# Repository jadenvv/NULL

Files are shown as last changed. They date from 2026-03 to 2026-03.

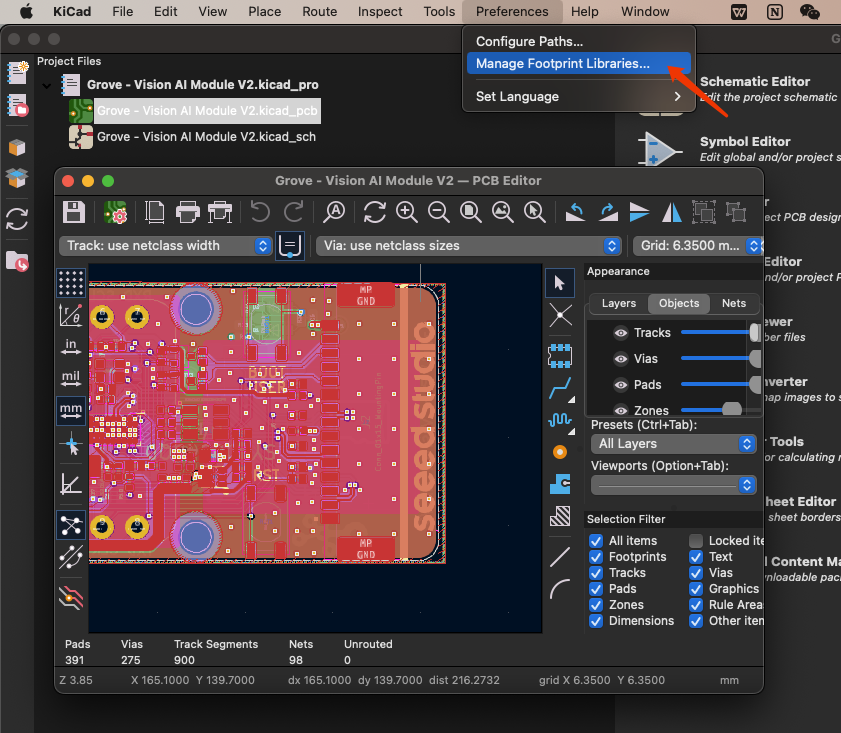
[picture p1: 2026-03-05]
null_elec/OPL_Kicad_Library-master/images/4.png

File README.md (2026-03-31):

# NULL: A Development Board for Pentesters
NULL is a ESP32-S3 based PCB board with capabilities of infrared emulation, RFID transceiving, ARP-spoofing on WiFi Networks, and LoRa Puck capabilities. Developed with a mixture of the ESP-IDF development environment 
## What was the motivation for NULL? 
The origins of the development of NULL really came out of the intrigue of the flipper zero. I wanted to create a cheaper alternative to what seemed like an amazing development board for pentesting enthuastist. And, not only did I create a cheaper alternative for myself, but added an additional feature of a LoRA puck boosting the overall usefullness of the board.
## Images of Schematic & Wiring 
Screenshot 2026-03-20 at 1 32 42 PM
4 Layer Board with the layout
<- SIGNAL  ->
<- GND  ->
<- POWER  ->
<- SIGNAL/GND  ->
Screenshot 2026-03-20 at 1 33 02 PM
Screenshot 2026-03-20 at 1 33 33 PM
Screenshot 2026-03-20 at 1 33 41 PM

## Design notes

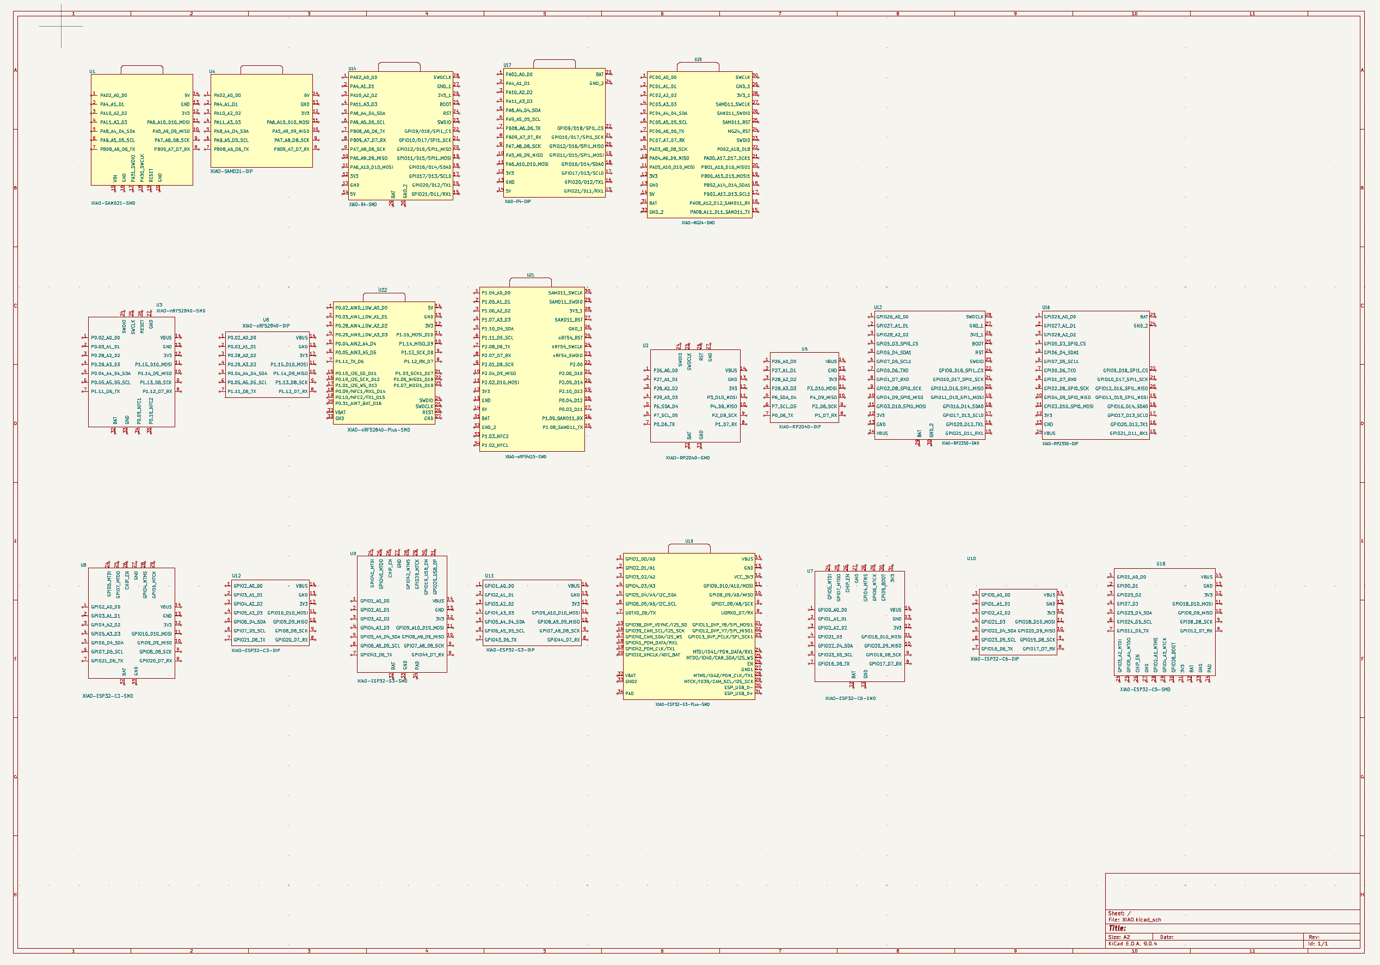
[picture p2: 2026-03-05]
null_elec/OPL_Kicad_Library-master/images/XIAO_Family_1.png

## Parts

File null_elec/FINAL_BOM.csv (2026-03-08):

JLCPCB BOM Tool - BOM Matching
BOM name：null-JLCPCB Assembly Order.xlsx |  | Download Time：2026-03-06 12:02:31 |  | * Our matching results are updated in real-time, but stock and prices may change. If it's been over 24 hours, please re-match before placing your order.
PCB Assembled Qty：5 |  | Est. Total Price：47.1463
Your BOM |  |  |  |  |  |  |  | Order Information
Top Designator | Comment | Footprint | Part # | Manufacturer | Footprint | Description | Category | JLCPCB Part # | Product link | Lib Type | Qty | Source | Total Price ($)
AE1 | Antenna | Connector_PinSocket_2.54mm:PinSocket_1x01_P2.54mm_Vertical
AE3 | Antenna | RF_Antenna:Molex_47948-0001_2.4Ghz | 479480001 | MOLEX | SMD,4x3.2mm | -40℃~+85℃ 100MHz 2.4GHz 2W 3.2mm 3.2mm 3.7dBi 50Ω Patch Antenna SMD,4x3.2mm Antennas ROHS | Antennas | C152351 | https://jlcpcb.com/partdetail/MOLEX-479480001/C152351 | Extended | 2 | 2 JLCPCB | 2.3406
C1,C4,C20,C21,C60 | 10uF | Capacitor_SMD:C_0805_2012Metric | GRM21BR61H106KE43L | Murata Electronics | 805 | 10uF 50V X5R ±10% 0805 Multilayer Ceramic Capacitors MLCC - SMD/SMT ROHS | Multilayer Ceramic Capacitors MLCC - SMD/SMT | C440198 |  | Basic | 14 | 14 JLCPCB | 0.9156
C2,C14,C28,C29,C32 | 1uF | Capacitor_SMD:C_0402_1005Metric | CL05A105KA5NQNC | Samsung Electro-Mechanics | 402 | 1uF 25V X5R ±10% 0402 Multilayer Ceramic Capacitors MLCC - SMD/SMT ROHS | Multilayer Ceramic Capacitors MLCC - SMD/SMT | C52923 | https://jlcpcb.com/partdetail/53938-CL05A105KA5NQNC/C52923 | Basic | 20 | 20 JLCPCB | 0.066
C3 | 10nF | Capacitor_SMD:C_0805_2012Metric | CL21B103KBANNNC | Samsung Electro-Mechanics | 805 | 10nF 50V X7R ±10% 0805 Multilayer Ceramic Capacitors MLCC - SMD/SMT ROHS | Multilayer Ceramic Capacitors MLCC - SMD/SMT | C1710 | https://jlcpcb.com/partdetail/2062-CL21B103KBANNNC/C1710 | Basic | 20 | 20 JLCPCB | 0.13
C5,C11,C22 | 1nF | Capacitor_SMD:C_0402_1005Metric | 0402B102K500NT | FH (Guangdong Fenghua Advanced Tech) | 402 | 1nF 50V X7R ±10% 0402 Multilayer Ceramic Capacitors MLCC - SMD/SMT ROHS | Multilayer Ceramic Capacitors MLCC - SMD/SMT | C1523 | https://jlcpcb.com/partdetail/1875-0402B102K500NT/C1523 | Basic | 20 | 20 JLCPCB | 0.024
C6,C7,C8,C9,C10,C30, C15,C16,C15,C16 | 0.1uF | Capacitor_SMD:C_0402_1005Metric | CL05B104KO5NNNC | Samsung Electro-Mechanics | 402 | 100nF 16V X7R ±10% 0402 Multilayer Ceramic Capacitors MLCC - SMD/SMT ROHS | Multilayer Ceramic Capacitors MLCC - SMD/SMT | C1525 | https://jlcpcb.com/partdetail/1877-CL05B104KO5NNNC/C1525 | Basic | 26 | 26 JLCPCB | 0.0338
C12,C13 | 12pF | Capacitor_SMD:C_0402_1005Metric | 0402CG120J500NT | FH (Guangdong Fenghua Advanced Tech) | 402 | 12pF 50V C0G ±5% 0402 Multilayer Ceramic Capacitors MLCC - SMD/SMT ROHS | Multilayer Ceramic Capacitors MLCC - SMD/SMT | C1547 | https://jlcpcb.com/partdetail/1899-0402CG120J500NT/C1547 | Basic | 20 | 20 JLCPCB | 0.022
C17,C18,C19 | 470nF | Capacitor_SMD:C_0402_1005Metric | CL05A474KP5NNNC | Samsung Electro-Mechanics | 402 | 10V 470nF X5R ±10% 0402 Multilayer Ceramic Capacitors MLCC - SMD/SMT ROHS | Multilayer Ceramic Capacitors MLCC - SMD/SMT | C47339 | https://jlcpcb.com/partdetail/48344-CL05A474KP5NNNC/C47339 | Extended | 20 | 20 JLCPCB | 0.084
C23 | 39pF | Capacitor_SMD:C_0402_1005Metric | 0402CG390J500NT | FH (Guangdong Fenghua Advanced Tech) | 402 | 39pF 50V C0G ±5% 0402 Multilayer Ceramic Capacitors MLCC - SMD/SMT ROHS | Multilayer Ceramic Capacitors MLCC - SMD/SMT | C1563 | https://jlcpcb.com/partdetail/1915-0402CG390J500NT/C1563 | Extended | 20 | 20 JLCPCB | 0.024
C24,C25 | 3.3pF | Capacitor_SMD:C_0402_1005Metric | 0402CG3R3C500NT | FH (Guangdong Fenghua Advanced Tech) | 402 | 3.3pF 50V C0G 0402 Multilayer Ceramic Capacitors MLCC - SMD/SMT ROHS | Multilayer Ceramic Capacitors MLCC - SMD/SMT | C1565 | https://jlcpcb.com/partdetail/1917-0402CG3R3C500NT/C1565 | Extended | 20 | 20 JLCPCB | 0.026
C26 | 4.7uF | Capacitor_SMD:C_0402_1005Metric | CL05A475MP5NRNC | Samsung Electro-Mechanics | 402 | 10V 4.7uF X5R ±20% 0402 Multilayer Ceramic Capacitors MLCC - SMD/SMT ROHS | Multilayer Ceramic Capacitors MLCC - SMD/SMT | C23733 | https://jlcpcb.com/partdetail/24469-CL05A475MP5NRNC/C23733 | Basic | 20 | 20 JLCPCB | 0.1
C27,C57 | 10uF | Capacitor_SMD:C_0402_1005Metric | CL05A106MQ5NUNC | Samsung Electro-Mechanics | 402 | 10uF 6.3V X5R ±20% 0402 Multilayer Ceramic Capacitors MLCC - SMD/SMT ROHS | Multilayer Ceramic Capacitors MLCC - SMD/SMT | C15525 | https://jlcpcb.com/partdetail/16204-CL05A106MQ5NUNC/C15525 | Basic | 20 | 20 JLCPCB | 0.11
C31,C33,C39,C41,C46,C58 | 2.2uF | Capacitor_SMD:C_0402_1005Metric | GRM155R60J225KE95D | Murata Electronics | 402 | 2.2uF 6.3V X5R ±10% 0402 Multilayer Ceramic Capacitors MLCC - SMD/SMT ROHS | Multilayer Ceramic Capacitors MLCC - SMD/SMT | C76992 | https://jlcpcb.com/partdetail/MurataElectronics-GRM155R60J225KE95D/C76992 | Extended | 22 | 22 JLCPCB | 0.176
C34,C40,C42,C47,C59 | 0.01uF | Capacitor_SMD:C_0402_1005Metric | CL05B103KB5NNNC | Samsung Electro-Mechanics | 402 | 10nF 50V X7R ±10% 0402 Multilayer Ceramic Capacitors MLCC - SMD/SMT ROHS | Multilayer Ceramic Capacitors MLCC - SMD/SMT | C15195 | https://jlcpcb.com/partdetail/15869-CL05B103KB5NNNC/C15195 | Basic | 20 | 20 JLCPCB | 0.028
C35,C36 | 1.6pF | Capacitor_SMD:C_0402_1005Metric | GJM1555C1H1R6WB01D | Murata Electronics | 402 | 1.6pF 50V C0G 0402 Multilayer Ceramic Capacitors MLCC - SMD/SMT ROHS | Multilayer Ceramic Capacitors MLCC - SMD/SMT | C88881 | https://jlcpcb.com/partdetail/MurataElectronics-GJM1555C1H1R6WB01D/C88881 | Extended | 8 | 8 JLCPCB | 0.464
C37,C38,C54 | 27pF | Capacitor_SMD:C_0402_1005Metric | GJM1555C1H270FB01D | Murata Electronics | 402 | 27pF 50V C0G ±1% 0402 Multilayer Ceramic Capacitors MLCC - SMD/SMT ROHS | Multilayer Ceramic Capacitors MLCC - SMD/SMT | C88883 | https://jlcpcb.com/partdetail/MurataElectronics-GJM1555C1H270FB01D/C88883 | Extended | 20 | 20 JLCPCB | 0.598
C43,C44 | 1500uF | Capacitor_SMD:C_0402_1005Metric | RX1500UF10V90RV0042 | KNSCHA | SMD,D10xL10.2mm | -55℃~+105℃ 10.2mm 10V 10mm 1500uF 2000hrs@105℃ ±20% SMD,D10xL10.2mm Aluminum Electrolytic Capacitors - SMD ROHS | Aluminum Electrolytic Capacitors - SMD | C2887277 | https://jlcpcb.com/partdetail/KNSCHA-RX1500UF10V90RV0042/C2887277 | Extended | 5 | 5 JLCPCB | 1.187
C45,C48 | 1200pF | Capacitor_SMD:C_0402_1005Metric | CC0402KRX7R9BB122 | YAGEO | 402 | 1.2nF 50V X7R ±10% 0402 Multilayer Ceramic Capacitors MLCC - SMD/SMT ROHS | Multilayer Ceramic Capacitors MLCC - SMD/SMT | C107021 | https://jlcpcb.com/partdetail/YAGEO-CC0402KRX7R9BB122/C107021 | Extended | 20 | 20 JLCPCB | 0.024
C49,C52 | 680pF | Capacitor_SMD:C_0402_1005Metric | 0402B681K500NT | FH (Guangdong Fenghua Advanced Tech) | 402 | 50V 680pF X7R ±10% 0402 Multilayer Ceramic Capacitors MLCC - SMD/SMT ROHS | Multilayer Ceramic Capacitors MLCC - SMD/SMT | C1541 | https://jlcpcb.com/partdetail/1893-0402B681K500NT/C1541 | Extended | 20 | 20 JLCPCB | 0.024
C50 | 10pF | Capacitor_SMD:C_0402_1005Metric | CL05C100JB5NNNC | Samsung Electro-Mechanics | 402 | 10pF 50V C0G ±5% 0402 Multilayer Ceramic Capacitors MLCC - SMD/SMT ROHS | Multilayer Ceramic Capacitors MLCC - SMD/SMT | C32949 | https://jlcpcb.com/partdetail/33914-CL05C100JB5NNNC/C32949 | Basic | 20 | 20 JLCPCB | 0.09
C51 | 220pF | Capacitor_SMD:C_0402_1005Metric | 0402B221K500NT | FH (Guangdong Fenghua Advanced Tech) | 402 | 220pF 50V X7R ±10% 0402 Multilayer Ceramic Capacitors MLCC - SMD/SMT ROHS | Multilayer Ceramic Capacitors MLCC - SMD/SMT | C1530 | https://jlcpcb.com/partdetail/1882-0402B221K500NT/C1530 | Basic | 20 | 20 JLCPCB | 0.024
C53 | 120pF | Capacitor_SMD:C_0402_1005Metric | 0402N121J500CT | Walsin Tech Corp | 402 | 120pF 50V NP0 ±5% 0402 Multilayer Ceramic Capacitors MLCC - SMD/SMT ROHS | Multilayer Ceramic Capacitors MLCC - SMD/SMT | C237176 | https://jlcpcb.com/partdetail/Walsin_TechCorp-0402N121J500CT/C237176 | Extended | 20 | 20 JLCPCB | 0.036
C55 | 82pF | Capacitor_SMD:C_0402_1005Metric | 0402CG820J500NT | FH (Guangdong Fenghua Advanced Tech) | 402 | 50V 82pF C0G ±5% 0402 Multilayer Ceramic Capacitors MLCC - SMD/SMT ROHS | Multilayer Ceramic Capacitors MLCC - SMD/SMT | C45501 | https://jlcpcb.com/partdetail/46503-0402CG820J500NT/C45501 | Extended | 20 | 20 JLCPCB | 0.024
C56 | 68pF | Capacitor_SMD:C_0402_1005Metric | CL05C680JB5NNNC | Samsung Electro-Mechanics | 402 | 50V 68pF C0G ±5% 0402 Multilayer Ceramic Capacitors MLCC - SMD/SMT ROHS | Multilayer Ceramic Capacitors MLCC - SMD/SMT | C14441 | https://jlcpcb.com/partdetail/15103-CL05C680JB5NNNC/C14441 | Extended | 20 | 20 JLCPCB | 0.092
D1 | IR26-21C_L110_TR8 | LED_SMD:LED_1206_3216Metric | IR26-21C/L110/TR8 | Everlight Elec | 1206 | -25℃~+85℃ 1.2V 1mW/sr@IF=20mA 940nm 1206 Infrared LED Emitters ROHS | Infrared LED Emitters | C73929 | https://jlcpcb.com/partdetail/EverlightElec-IR26_21C_L110TR8/C73929 | Extended | 6 | 6 JLCPCB | 0.2892
D2 | ESD9B3.3ST5G | Diode_SMD:D_SOD-923 | ESD9B3.3ST5G | GOODWORK | SOD-923 | -55℃~+150℃ 1 100W 10pF 12.5V 3.3V 4.3V 500nA 8A ESD IEC 61000-4-2 SOD-923 ESD and Surge Protection (TVS/ESD) ROHS | ESD And Surge Protection (TVS/ESD) | C41364470 | https://jlcpcb.com/partdetail/GOODWORK-ESD9B33ST5G/C41364470 | Extended | 20 | 20 JLCPCB | 0.376
D3 | 1N4148 | Diode_THT:D_DO-35_SOD27_P7.62mm_Horizontal | 1N4148 | Changzhou Starsea Elec | DO-35 | -65℃~+200℃@(Tj) 100V 150mA 1V@10mA 4ns 500mA 500mW 5uA@75V DO-35 Switching Diodes ROHS | Switching Diodes | C85057 | https://jlcpcb.com/partdetail/Changzhou_StarseaElec-1N4148/C85057 | Extended | 7 | 7 JLCPCB | 0.0854
IC1 | TRF7970ARHBR | trt:QFN50P500X500X100-33N-D | TRF7970ARHBR | Texas Instruments | VQFN-32-EP(5x5) | 106Kbit/s、212Kbit/s、424Kbit/s、848Kbit/s 13.56MHz 2.7V~5.5V FeliCa,ISO 14443A,ISO 14443B,ISO 15693,ISO 18000-3,ISO 21481,MIFARE,NFC SPI VQFN-32-EP(5x5) RFID ICs ROHS | RFID ICs | C117004 | https://jlcpcb.com/partdetail/TexasInstruments-TRF7970ARHBR/C117004 | Extended | 2 | 2 JLCPCB | 3.8788
J1 | USB_C_Receptacle_USB2.0_14P | Connector_USB:USB_C_Receptacle_HCTL_HC-TYPE-C-16P-01A | HC-TYPE-C-16P-01A | HCTL | SMD | -55℃~+85℃ 1 16P 20V 5A 7.35mm Black Female Surface Mount, Right Angle Type-C SMD USB Connectors ROHS | USB Connectors | C2894897 | https://jlcpcb.com/partdetail/HCTL-HC_TYPE_C_16P01A/C2894897 | Extended | 2 | 2 JLCPCB | 0.1966
L1 | 2.0nH | Inductor_SMD:L_0402_1005Metric | LQG15HS2N0S02D | Murata Electronics | 402 | 2nH 6GHz 8@100MHz 900mA 90mΩ 0402 Inductors (SMD) ROHS | Inductors (SMD) | C18216 | https://jlcpcb.com/partdetail/MurataElectronics-LQG15HS2N0S02D/C18216 | Extended | 20 | 20 JLCPCB | 0.2
L2 | 150nH | Inductor_SMD:L_0402_1005Metric | LQG15HSR15J02D | Murata Electronics | 402 | 150mA 150nH 2.99Ω 550MHz 8@100MHz Multilayer inductor ±5% 0402 Inductors (SMD) ROHS | Inductors (SMD) | C162548 | https://jlcpcb.com/partdetail/MurataElectronics-LQG15HSR15J02D/C162548 | Extended | 20 | 20 JLCPCB | 0.194
L3,L4 | 15uH | Inductor_SMD:L_0402_1005Metric | LQW15DN150M00D | Murata Electronics | 402 | 100mA 100mA 15uH 6.555Ω ±20% 0402 Power Inductors ROHS | Inductors (SMD) | C3221788 | https://jlcpcb.com/partdetail/ChilisinElec-SDT0402T_150MN/C329840 | Extended | 8 | 8 JLCPCB | 9.71
L5 | 9.1nH | Inductor_SMD:L_0402_1005Metric | LQG15HS9N1J02D | Murata Electronics | 402 | 260mΩ 3.4GHz 500mA 8@100MHz 9.1nH Multilayer inductor ±5% 0402 Inductors (SMD) ROHS | Inductors (SMD) | C162547 | https://jlcpcb.com/partdetail/MurataElectronics-LQG15HS9N1J02D/C162547 | Extended | 20 | 20 JLCPCB | 0.176
L6 | 2.6nH | Inductor_SMD:L_0402_1005Metric | LQG15WZ2N6B02D | Murata Electronics | 402 | 2.6nH 23@250MHz 6.5GHz 70mΩ 900mA AEC-Q200 0402 Inductors (SMD) ROHS | Inductors (SMD) | C1012745 | https://jlcpcb.com/partdetail/MurataElectronics-LQG15WZ2N6B02D/C1012745 | Extended | 5 | 5 JLCPCB | 0.4495
L7 | 330nH | Inductor_SMD:L_0402_1005Metric | VHF100505HQR33JT | FH (Guangdong Fenghua Advanced Tech) | 402 | 330nH 350MHz 50mA 6@50MHz 7Ω ±5% 0402 Inductors (SMD) ROHS | Inductors (SMD) | C485776 | https://jlcpcb.com/partdetail/494209-VHF100505HQR33JT/C485776 | Extended | 20 | 20 JLCPCB | 0.206
L8 | 4.7uH | Inductor_SMD:L_0402_1005Metric | IHLP1616BZER4R7M5A | Vishay Intertech | SMD,4.5x4.1mm | 1.8A 110mΩ 4.7uH AEC-Q200 ±20% SMD,4.5x4.1mm Power Inductors ROHS | Power Inductors | C3223759 | https://jlcpcb.com/partdetail/VishayIntertech-IHLP1616BZER4R7M5A/C3223759 | Extended | 5 | 5 JLCPCB | 2.527
Q1 | PN2222A | Package_TO_SOT_THT:TO-92_Inline | PN2222ABU | onsemi | TO-92-3L | -55℃~+150℃ 1 NPN 10uA 1A 300MHz 300mV 35 40V 625mW 6V NPN TO-92-3L Bipolar (BJT) ROHS | Bipolar (BJT) | C896866 | https://jlcpcb.com/partdetail/onsemi-PN2222ABU/C896866 | Extended | 4 | 4 JLCPCB | 0.4316
R1,R2,R3,R5,R6,R22 | 0 | Resistor_SMD:R_0402_1005Metric | 0402WGF0000TCE | UNI-ROYAL(Uniroyal Elec) | 402 | -55℃~+155℃ 0Ω 50V 62.5mW Thick Film Resistor ±1% ±800ppm/℃ 0402 Chip Resistor - Surface Mount ROHS | Chip Resistor - Surface Mount | C17168 | https://jlcpcb.com/partdetail/17853-0402WGF0000TCE/C17168 | Basic | 22 | 22 JLCPCB | 0.0198
R4,R14,R15,R16,R18,R19,R20,R21,R26,R27,R28 | 10K | Resistor_SMD:R_0402_1005Metric | 0402WGF1002TCE | UNI-ROYAL(Uniroyal Elec) | 402 | -55℃~+155℃ 10kΩ 50V 62.5mW Thick Film Resistor ±1% ±100ppm/℃ 0402 Chip Resistor - Surface Mount ROHS | Chip Resistor - Surface Mount | C25744 | https://jlcpcb.com/partdetail/26487-0402WGF1002TCE/C25744 | Basic | 32 | 32 JLCPCB | 0.0256
R7,R8 | 5.1K | Resistor_SMD:R_0402_1005Metric | 0402WGF5101TCE | UNI-ROYAL(Uniroyal Elec) | 402 | -55℃~+155℃ 5.1kΩ 50V 62.5mW Thick Film Resistor ±1% ±100ppm/℃ 0402 Chip Resistor - Surface Mount ROHS | Chip Resistor - Surface Mount | C25905 | https://jlcpcb.com/partdetail/26648-0402WGF5101TCE/C25905 | Basic | 20 | 20 JLCPCB | 0.016
R9,R11 | 22 | Resistor_SMD:R_0402_1005Metric | 0402WGF220JTCE | UNI-ROYAL(Uniroyal Elec) | 402 | -55℃~+155℃ 22Ω 50V 62.5mW Thick Film Resistor ±1% ±100ppm/℃ 0402 Chip Resistor - Surface Mount ROHS | Chip Resistor - Surface Mount | C25092 | https://jlcpcb.com/partdetail/25835-0402WGF220JTCE/C25092 | Basic | 20 | 20 JLCPCB | 0.016
R10 | 100 | Resistor_SMD:R_0402_1005Metric | 0402WGF1000TCE | UNI-ROYAL(Uniroyal Elec) | 402 | -55℃~+155℃ 100Ω 50V 62.5mW Thick Film Resistor ±1% ±100ppm/℃ 0402 Chip Resistor - Surface Mount ROHS | Chip Resistor - Surface Mount | C25076 | https://jlcpcb.com/partdetail/25819-0402WGF1000TCE/C25076 | Basic | 20 | 20 JLCPCB | 0.016
R12 | 50 | Resistor_SMD:R_0402_1005Metric | AC0402JR-0750RL | YAGEO | 402 | -55℃~+155℃ 50V 50Ω 62.5mW Thick Film Resistor ±100ppm/℃ ±5% 0402 Chip Resistor - Surface Mount ROHS | Chip Resistor - Surface Mount | C227387 | https://jlcpcb.com/partdetail/YAGEO-AC0402JR0750RL/C227387 | Extended | 20 | 20 JLCPCB | 0.018
R13 | 650 | Resistor_SMD:R_0402_1005Metric | ERJ2RKF6650X | PANASONIC | 402 | -55℃~+155℃ 100mW 50V 665Ω Thick Film Resistor ±1% ±100ppm/℃ 0402 Chip Resistor - Surface Mount ROHS | Chip Resistor - Surface Mount | C2076870 | https://jlcpcb.com/partdetail/PANASONIC-ERJ2RKF6650X/C2076870 | Extended | 20 | 20 JLCPCB | 0.11
R17 | 390K | Resistor_SMD:R_0402_1005Metric | RCT02390KJLF | HKR(Hong Kong Resistors) | 402 | -55℃~+155℃ 390kΩ 50V 62.5mW Thick Film Resistor ±200ppm/℃ ±5% 0402 Chip Resistor - Surface Mount ROHS | Chip Resistor - Surface Mount | C174227 | https://jlcpcb.com/partdetail/185617-RCT02390KJLF/C174227 | Extended | 20 | 20 JLCPCB | 0.04
R23 | 750 | Resistor_SMD:R_0402_1005Metric | RCA02750RFLF | HKR(Hong Kong Resistors) | 402 | -55℃~+155℃ 50V 62.5mW 750Ω Thick Film Resistor ±1% ±200ppm/℃ 0402 Chip Resistor - Surface Mount ROHS |  | C22369358 | https://jlcpcb.com/partdetail/23848388-RCA02750RFLF/C22369358 | Extended | 7 | 7 JLCPCB | 0.0042
SW1 | SW_SPST | Button_Switch_SMD:SW_SPST_SKQG_WithStem | SKQGAKE010 | ALPSALPINE | SMD-4P,5.2x5.2mm | -30℃~+85℃ 1.5mm 100,000 cycles 12V 3.43N 5.2mm 5.2mm 50mA No Round Button SMD(SMT) Tab SPST Surface Mount,Vertical Without Bracket SMD-4P,5.2x5.2mm Tactile Switches ROHS | Tactile Switches | C127478 | https://jlcpcb.com/partdetail/ALPSALPINE-SKQGAKE010/C127478 | Extended | 5 | 5 JLCPCB | 0.869
SW2,SW3,SW4,SW5 | SW_Push | Button_Switch_SMD:SW_Tactile_SPST_NO_Straight_CK_PTS636Sx25SMTRLFS | PTS636SM43LFS | C&K | 插件,6x3.5mm | -40℃~+90℃ 1.8N 12V 3.5mm 50mA 6mm IP40 No PC Pin Rectangular Button SPST-NO Through Hole 插件,6x3.5mm Tactile Switches ROHS | Tactile Switches | C2689636 | https://jlcpcb.com/partdetail/CK-PTS636SM43LFS/C2689636 | Extended | 12 | 12 JLCPCB | 2.4696
U1 | W25Q32JVSS | Package_SO:SOIC-8_5.3x5.3mm_P1.27mm | W25Q32JVSSIQ | Winbond Elec | SOIC-8-208mil | -40℃~+85℃ 100,000 cycles 10uA 120ms@(32KB) 133MHz 2.7V~3.6V 20 Years 32Mbit 3ms SPI SOIC-8-208mil NOR FLASH ROHS | NOR FLASH | C82344 | https://jlcpcb.com/partdetail/WinbondElec-W25Q32JVSSIQ/C82344 | Extended | 2 | 2 JLCPCB | 3.007
U2 | ESP32-S3 | Package_DFN_QFN:QFN-56-1EP_7x7mm_P0.4mm_EP4x4mm | ESP32-S3 | Espressif Systems | QFN-56-EP(7x7) | -40℃~+105℃ -98.4dBm 150Mbps 2.412GHz~2.484GHz 2.4GHz 21dBm 340mA 3V~3.6V 88mA SPI、USB、UART、ADC、I2C、I2S、PWM WiFi transceiver QFN-56-EP(7x7) RF Transceiver ICs ROHS | RF Transceiver ICs | C2913192 | https://jlcpcb.com/partdetail/EspressifSystems-ESP32S3/C2913192 | Extended | 2 | 2 JLCPCB | 5.9952
U3 | TSOP343xx | OptoDevice:Vishay_MOLD-3Pin | TSOP4838 | Vishay Intertech | SIP-3-2.54mm | -25℃~+85℃ 2.5V~5.5V 38kHz 45m 45° 700uA SIP-3-2.54mm Infrared Remote Receiver (IRM) ROHS | Infrared Remote Receiver (IRM) | C124647 | https://jlcpcb.com/partdetail/VishayIntertech-TSOP4838/C124647 | Extended | 2 | 2 JLCPCB | 2.407
U5 | SX1262IMLTRT | Package_DFN_QFN:QFN-24-1EP_4x4mm_P0.5mm_EP2.6x2.6mm | SX1262IMLTRT | SEMTECH | QFN-24-EP(4x4) | -148dBm -40℃~+85℃ 1.8V~3.7V 150MHz~960MHz 22dBm 300Kbps 32mA 4.2mA ISM SPI transceiver QFN-24-EP(4x4) RF Transceiver ICs ROHS | RF Transceiver ICs | C191341 | https://jlcpcb.com/partdetail/SEMTECH-SX1262IMLTRT/C191341 | Extended | 2 | 2 JLCPCB | 6.592
U6 | PE4259 | Package_TO_SOT_SMD:SOT-363_SC-70-6 | PE4259-63 | pSemi | SC-70-6 | -40℃~+85℃ 0.35dB 1.8V~3.3V 10MHz~3GHz 30dB 33.5dBm SPDT SC-70-6 RF Switches ROHS | RF Switches | C470892 | https://jlcpcb.com/partdetail/pSemi-PE425963/C470892 | Extended | 2 | 2 JLCPCB | 1.232
U7 | NCP1117-3.3_SOT223 | Package_TO_SOT_SMD:SOT-223-3_TabPin2 | AMS1117-3.3(SOT-223) | HXY MOSFET | SOT-223 | 0℃~+125℃@(Ta) 1 1.4V@(1A) 15V 1A 3.3V Fixed Positive SOT-223 Voltage Regulators - Linear, Low Drop Out (LDO) Regulators ROHS | Voltage Regulators - Linear, Low Drop Out (LDO) Regulators | C5346136 | https://jlcpcb.com/partdetail/HXYMOSFET-AMS1117_3_3_SOT_223/C5346136 | Extended | 6 | 6 JLCPCB | 0.2412
U8 | TPS61222DCK | Package_TO_SOT_SMD:Texas_R-PDSO-G6 | TPS61222DCKR | Texas Instruments | SC-70-6(SOT-363) | -40℃~+125℃@(TJ) 1 200mA 5V 700mV~5.5V Boost Boost Built-in Fixed Yes SC-70-6(SOT-363) DC-DC Converters ROHS | DC-DC Converters | C116461 | https://jlcpcb.com/partdetail/TexasInstruments-TPS61222DCKR/C116461 | Extended | 2 | 2 JLCPCB | 1.115
U9 | APS6404L-3SQRx-SN | Package_SO:SOIC-8_3.9x4.9mm_P1.27mm | APS6404L-3SQR-SN | AP Memory | SOP-8 | SOP-8 PSRAM ROHS | DRAM | C5333729 | https://jlcpcb.com/partdetail/APMemory-APS6404L_3SQRSN/C5333729 | Extended | 2 | 2 JLCPCB | 5.1266
Y1 | 40MHz | Crystal:Crystal_SMD_3225-4Pin_3.2x2.5mm | X3S040000B81H-R | HELE(Harmony Elec) | SMD3225-4P | -20℃~+75℃ 40MHz 8pF ±10ppm ±10ppm SMD3225-4P Crystals ROHS | Crystals | C254377 | https://jlcpcb.com/partdetail/HELE_Harmony_Elec-X3S040000B81HR/C254377 | Extended | 5 | 5 JLCPCB | 1.086
Y2 | 32MHz | Crystal:Crystal_SMD_3225-4Pin_3.2x2.5mm | SX3B32.000F1010F30 | Shenzhen SCTF Elec | SMD3225-4P | -40℃~+85℃ 10pF 30Ω 32MHz Crystal Oscillator ±10ppm ±30ppm SMD3225-4P Crystals ROHS | Crystals | C2901705 | https://jlcpcb.com/partdetail/3151518-SX3B32000F1010F30/C2901705 | Extended | 6 | 6 JLCPCB | 0.4686
Y3 | 27.12MHz | Crystal:Crystal_SMD_3225-4Pin_3.2x2.5mm | K3A271201810 | KYX | SMD3225-4P | -40℃~+85℃ 18pF 27.12MHz 40Ω Crystal Oscillator ±10ppm ±20ppm SMD3225-4P Crystals ROHS | Crystals | C2875572 | https://jlcpcb.com/partdetail/KYX-K3A271201810/C2875572 | Extended | 6 | 6 JLCPCB | 0.4086
FL1 | 0900FM15K0039 | RF_Converter:Balun_Johanson_0900FM15K0039 | 0900FM15K0039001E | Johanson Dielectrics | 0900FM15K0039 | RF_Converter:Balun_Johanson_0900FM15K0039 | Balun |  | https://www.digikey.com/en/products/detail/johanson-technology-inc/0900FM15K0039001E/16639329 |  | 6 | 6 DigiKey | 2.76
AE4 | 0.950uH | RF_Antenna:Coilcraft_MA5532-AE_RFID | MA5532-AE | CoilCraft | 0.950uH | RF_Antenna:Coilcraft_MA5532-AE_RFID | RFID ICs |  | https://www.coilcraft.com/en-us/products/rf/rfid-transponders/x-y-axis-transponder-coil-2mhz/ma5532/ |  | 2 | 2 CoilCraft | 2.94
DS1 | OLED-128O064D | Display:OLED-128O064D | O128O064DBPP3N0000 | Vishay Dale | OLED-128O064D | Display:OLED-128O064D | DIsplay Oled |  | https://www.digikey.com/en/products/detail/vishay-dale/O128O064DBPP3N0000/7041855 |  | 2 | 2 DigiKey | 22.20

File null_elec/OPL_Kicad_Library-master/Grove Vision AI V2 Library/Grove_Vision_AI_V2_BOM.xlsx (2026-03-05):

Layer Jump | Number | Name | Specification | Operating Temperature | MPN Code | Quantity | Base | Plug Position | Process
N | 301010000 | SMD RES 0R-5%-1/16W;0402 |  | -55°C to 155°C | RC0402JR-070RL | 3 | 1 | R29,R30,R39 | SMT1
N | 301010004 | SMD RES 10K-5%-1/16W;0402 |  | -55°C to 155°C | RC0402JR-0710KL | 7 | 1 | R5,R7,R8,R23,R24,R31,R38 | SMT1
N | 301010008 | SMD RES 510K-5%-1/16W;0402 |  | -55°C to 155°C | RC0402JR-07510KL | 1 | 1 | R35 | SMT1
N | 301010456 | SMD RES 100K-1%-1/16W;0402 |  | -55°C to 155°C | RC0402FR-07100KL | 7 | 1 | R6,R10,R11,R16,R32,R33,R37 | SMT1
N | 301010495 | SMD RES;5.1K-1%-1/16W;0402 |  | -55°C to 155°C | RC0402FR-075K1L | 3 | 1 | R2,R3,R36 | SMT1
N | 301010746 | SMD RES 2.2K-1%-1/16W;0402 |  | -55°C to 155°C | RC0402FR-072K2L | 10 | 1 | R1,R4,R13,R14,R15,R19,R20,R21,R22,R40 | SMT1
N | 301011331 | SMD RES 22.1K-1%-1/16W;0402 |  | -55°C to 155°C | RC0402FR-0722K1L | 2 | 1 | R26,R34 | SMT1
N | 302010004 | SMD CAP Ceramic 100nF-16V-10%-X7R;0402 |  | -55°C to 125°C | CC0402KRX7R7BB104 | 18 | 1 | C5,C8,C13,C20,C21,C22,C23,C24,C25,C26,C27,C29,C30,C31,C32,C35,C36,C39 | SMT1
N | 302010006 | SMD CAP Ceramic 10nF-50V-10%-X7R;0402 |  | -55°C to 125°C | CC0402KRX7R9BB103 | 1 | 1 | C3 | SMT1
N | 302010049 | SMD CAP Ceramic 12pF-50V-5%-NPO;0402 |  | -55°C to 125°C | CC0402JRNPO9BN120 | 2 | 1 | C14,C15 | SMT1
N | 302010051 | SMD CAP Ceramic 220nF-16V-10%-X7R;0402 |  | -55°C to 125°C | CC0402KRX7R7BB224 | 1 | 1 | C16 | SMT1
N | 302010407 | SMD CAP Ceramic 4.7uF-10V-10%-X5R;0402 |  | -55°C to 85°C | CC0402KRX5R6BB475 | 7 | 1 | C4,C6,C7,C9,C10,C28,C34 | SMT1
N | 302010519 | SMD CAP Ceramic 10uF-10V-20%-X5R;0402 |  | -55°C to 85°C | CC0402MRX5R6BB106 | 2 | 1 | C11,C37 | SMT1
N | 302013249 | SMD CAP Ceramic 1uF-10V-10%-X5R;0402 |  | -55°C to 85°C | CL05A105KP5NNNC | 5 | 1 | C1,C2,C17,C18,C19 | SMT1
N | 303010544 | SMD Inductor 4.7uH-20%-1.1A;0806 |  | -40°C to 105°C | VLS201610HBX-4R7M-1 | 1 | 1 | L1 | SMT1
N | 303011858 | SMD Inductor 470nH-20%-2.6A;0603 |  | -40°C to 125°C | TFM160808ALC-R47MTAA | 2 | 1 | L2,L3 | SMT1
N | 304011053 | SMD Diode Schottky 40V-1A;SOD-323 |  |  | B5819WS SL | 4 | 1 | D1,D2,D3,D4 | SMT1
N | 304090121 | SMD LED Clear-Green;0402 | As posted |  | BL-HGE37A-AV-TRB | 1 | 1 | LED2 | SMT1
N | 304090746 | SMD LED Clear-Yellow;0402 | As posted |  | 16-213/Y2C-AN2Q1B/3T | 1 | 1 | LED1 | SMT1
N | 305030071 | SMD MOSFET N-CH 20V-500mA;SOT-523 |  |  | CJ1012 | 5 | 1 | Q1,Q2,Q3,Q4,Q5 | SMT1
N | 306011444 | SMD Crystal;24MHz-12pF-10ppm-4P-2.0*1.6*0.5mm |  | -40°C to 85°C | Y2400FE001 | 1 | 1 | X1 | SMT1
N | 310011697 | SMD IC MCU;Dual Cortex-M55 Core(Max 400MHz)-With a 400MHz NPU;WLCSP-65 | L5.58*W2.27mm | -40°C to 85°C | HX6538-A01TWA | 1 | 1 | U1 | SMT1
N | 310032794 | SMD IC PMIC;DCDC Buck-ADJ-2.2MHz-4A;DFN1.5×1.5-6 |  | -40°C to 85°C | SY80004DQD | 2 | 1 | U4,U6 | SMT1
N | 310032813 | SMD IC PMIC;LDO-1.8V-300mA;XTDFN-1*1-4L |  | -40°C to 125°C | SGM2036S-1.8XXDH4G/TR | 1 | 1 | U3 | SMT1
N | 310071431 | SMD IC Interface USB to High Speed TTL;QFN16 | USB to High-Speed Serial Port | -40°C to 85°C | CH343P | 1 | 1 | U2 | SMT1
N | 310091468 | SMD IC Memory;128Mbit-1.8V;SOIC-8 |  | -40°C to 85°C | W25Q128JWSIQ | 1 | 1 | U5 | SMT1
N | 311020009 | SMD Top Button 4N;4P-L4.6*W3.2*H2.5mm |  | -20°C to 70°C | SKRPADE010 | 1 | 1 | RST1 | SMT1
N | 311020518 | SMD Top Button 1.57N;4P-L4.6*W3.2*H2.5mm |  | -30°C to 85°C | SKRPABE010 | 1 | 1 | BOOT1 | SMT1
N | 312030502 | SMD DIGITAL MIC OMNI -26dBFS;OCLGA-4:3.5*2.65*0.94mm |  | -40˚C to 100˚C | MSM261D3526H1CPM | 1 | 1 | MIC1 | SMT1
N | 319015667 | PCB;Grove - Vision AI Module V2 -蓝油白字-4层 | 20*40*1.6mm-ENIG-FR4;Steel mesh code；404012305 |  |  | 1 | 1 |  | SMT1
N | 320011358 | SMD USB TYPE C-W/P;12+4P-8.94*7.35*3.26mm |  | -30°C to 85°C | USB-31C-F-16P-L7.35 | 1 | 1 | J1 | SMT1
N | 320031231 | DIP Black Female Header VERT;1*7P-2.54-5.0mm |  | -40℃ to 105℃ |  | 2 | 1 | P8,P9 | Unit
N | 320060904 | SMD FPC CONN Bottom Contact;15P-1.0mm;L19.9*W6.76*H2.0mm |  | -30°C to 85°C | ST-FPC-W102015-D | 1 | 1 | J2 | SMT1
N | 320090535 | SMD uSD Card Holder;9+4P-L11.25*W6.96*H1.42mm |  | -25°C to 70°C | ST-TF-MR267 | 1 | 1 | J5 | SMT1
N | 320110032 | SMD Grove Female Header-Beige;4P-2.0-90D | 2.0-4PHorizontal Mount with Locking Socket |  | PHS-4A horizontal mount | 1 | 1 | J3 | SMT1

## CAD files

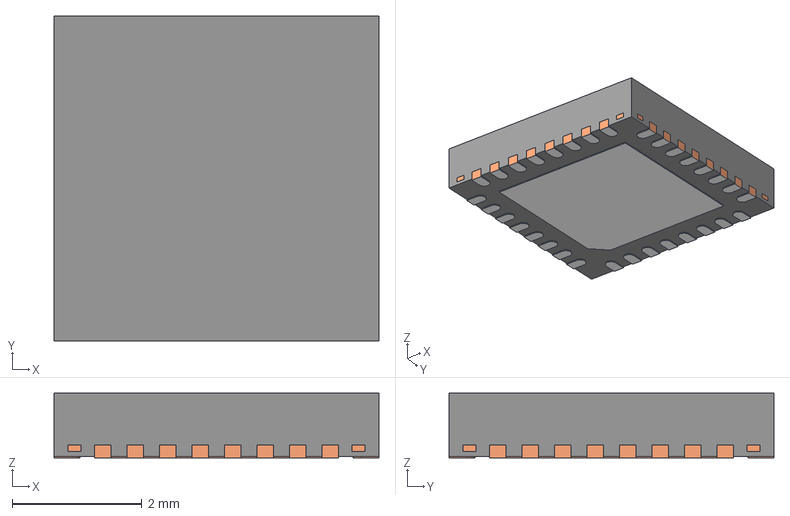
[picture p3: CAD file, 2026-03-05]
null_elec/LIB_TRF7970ARHBR/TRF7970ARHBR/3D/TRF7970ARHBR.stp
5.00 x 5.00 x 1.00 mm
BODY-QFN
FRAME-RHB0032E
PIN1-ID

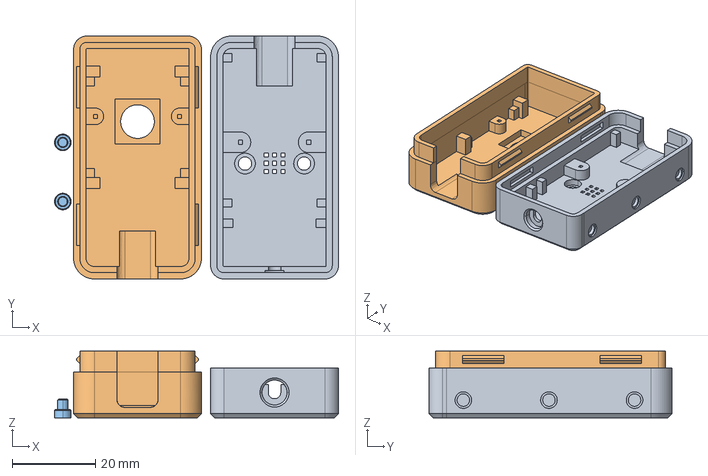
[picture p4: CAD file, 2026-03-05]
null_elec/OPL_Kicad_Library-master/Grove Vision AI V2 Library/himax.stp
68.4 x 58.5 x 16.1 mm

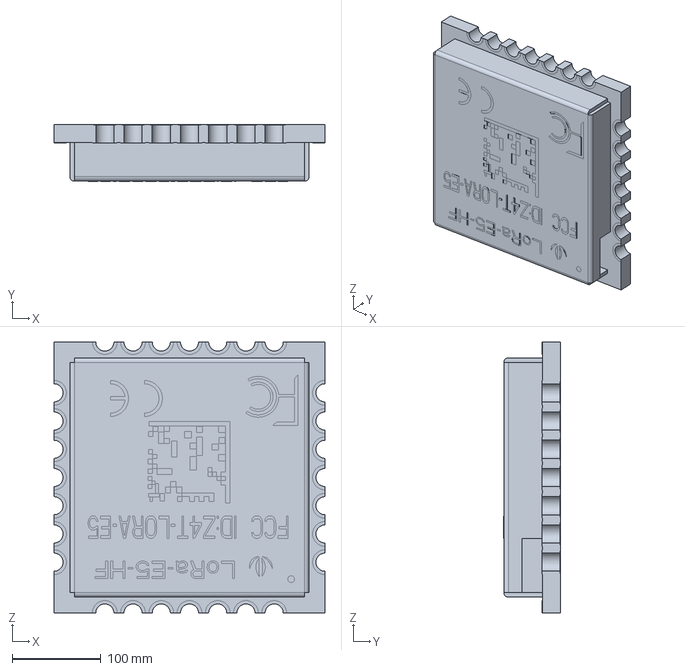
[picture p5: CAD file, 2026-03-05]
null_elec/OPL_Kicad_Library-master/Seeed Studio Wio Series/Wio-E5-LE/LoRa-E5-LE-HF_3D_File.stp
304.8 x 63.8 x 304.8 mm

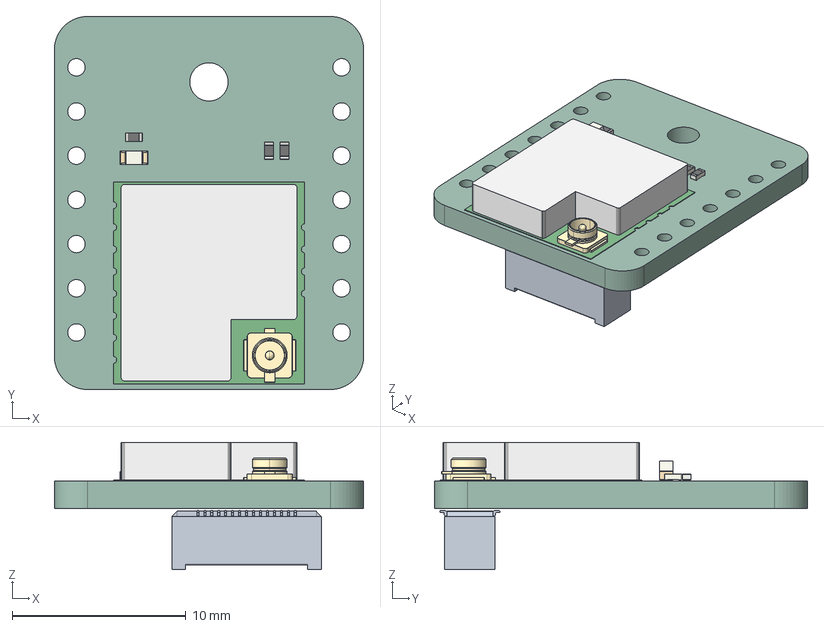
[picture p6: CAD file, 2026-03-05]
null_elec/OPL_Kicad_Library-master/Seeed Studio Wio Series/Wio-SX1262/Wio-SX1262_for_XIAO_3D_file.step
17.8 x 21.4 x 7.30 mm
R_0402_1005Metric x 3
LED_0603_1608Metric
PCB
BF04-30pin-35H
Wio-SX1262 for XIAO V1.0_PCB

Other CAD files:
null_elec/LIB_TRF7970ARHBR/TRF7970ARHBR/3D/TRF7970ARHBR.stl
null_elec/LIB_TRF7970ARHBR/TRF7970ARHBR/Allegro/qfn50p500x500x100-33n-d.psm
null_elec/LIB_TRF7970ARHBR/TRF7970ARHBR/DEHDL/trf7970arhbr/chips/chips.prt
null_elec/OPL_Kicad_Library-master/Grove Vision AI V2 Library/himax.3mf

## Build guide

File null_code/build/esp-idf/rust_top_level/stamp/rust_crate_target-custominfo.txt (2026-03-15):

# This is a generated file and its contents are an internal implementation detail.
# The download step will be re-executed if anything in this file changes.
# No other meaning or use of this file is supported.

method=custom
command=
source_dir=/home/jadenv/Documents/NULL/null_code/components/rust_top_level/rust_crate
work_dir=/home/jadenv/Documents/NULL/null_code/build/esp-idf/rust_top_level

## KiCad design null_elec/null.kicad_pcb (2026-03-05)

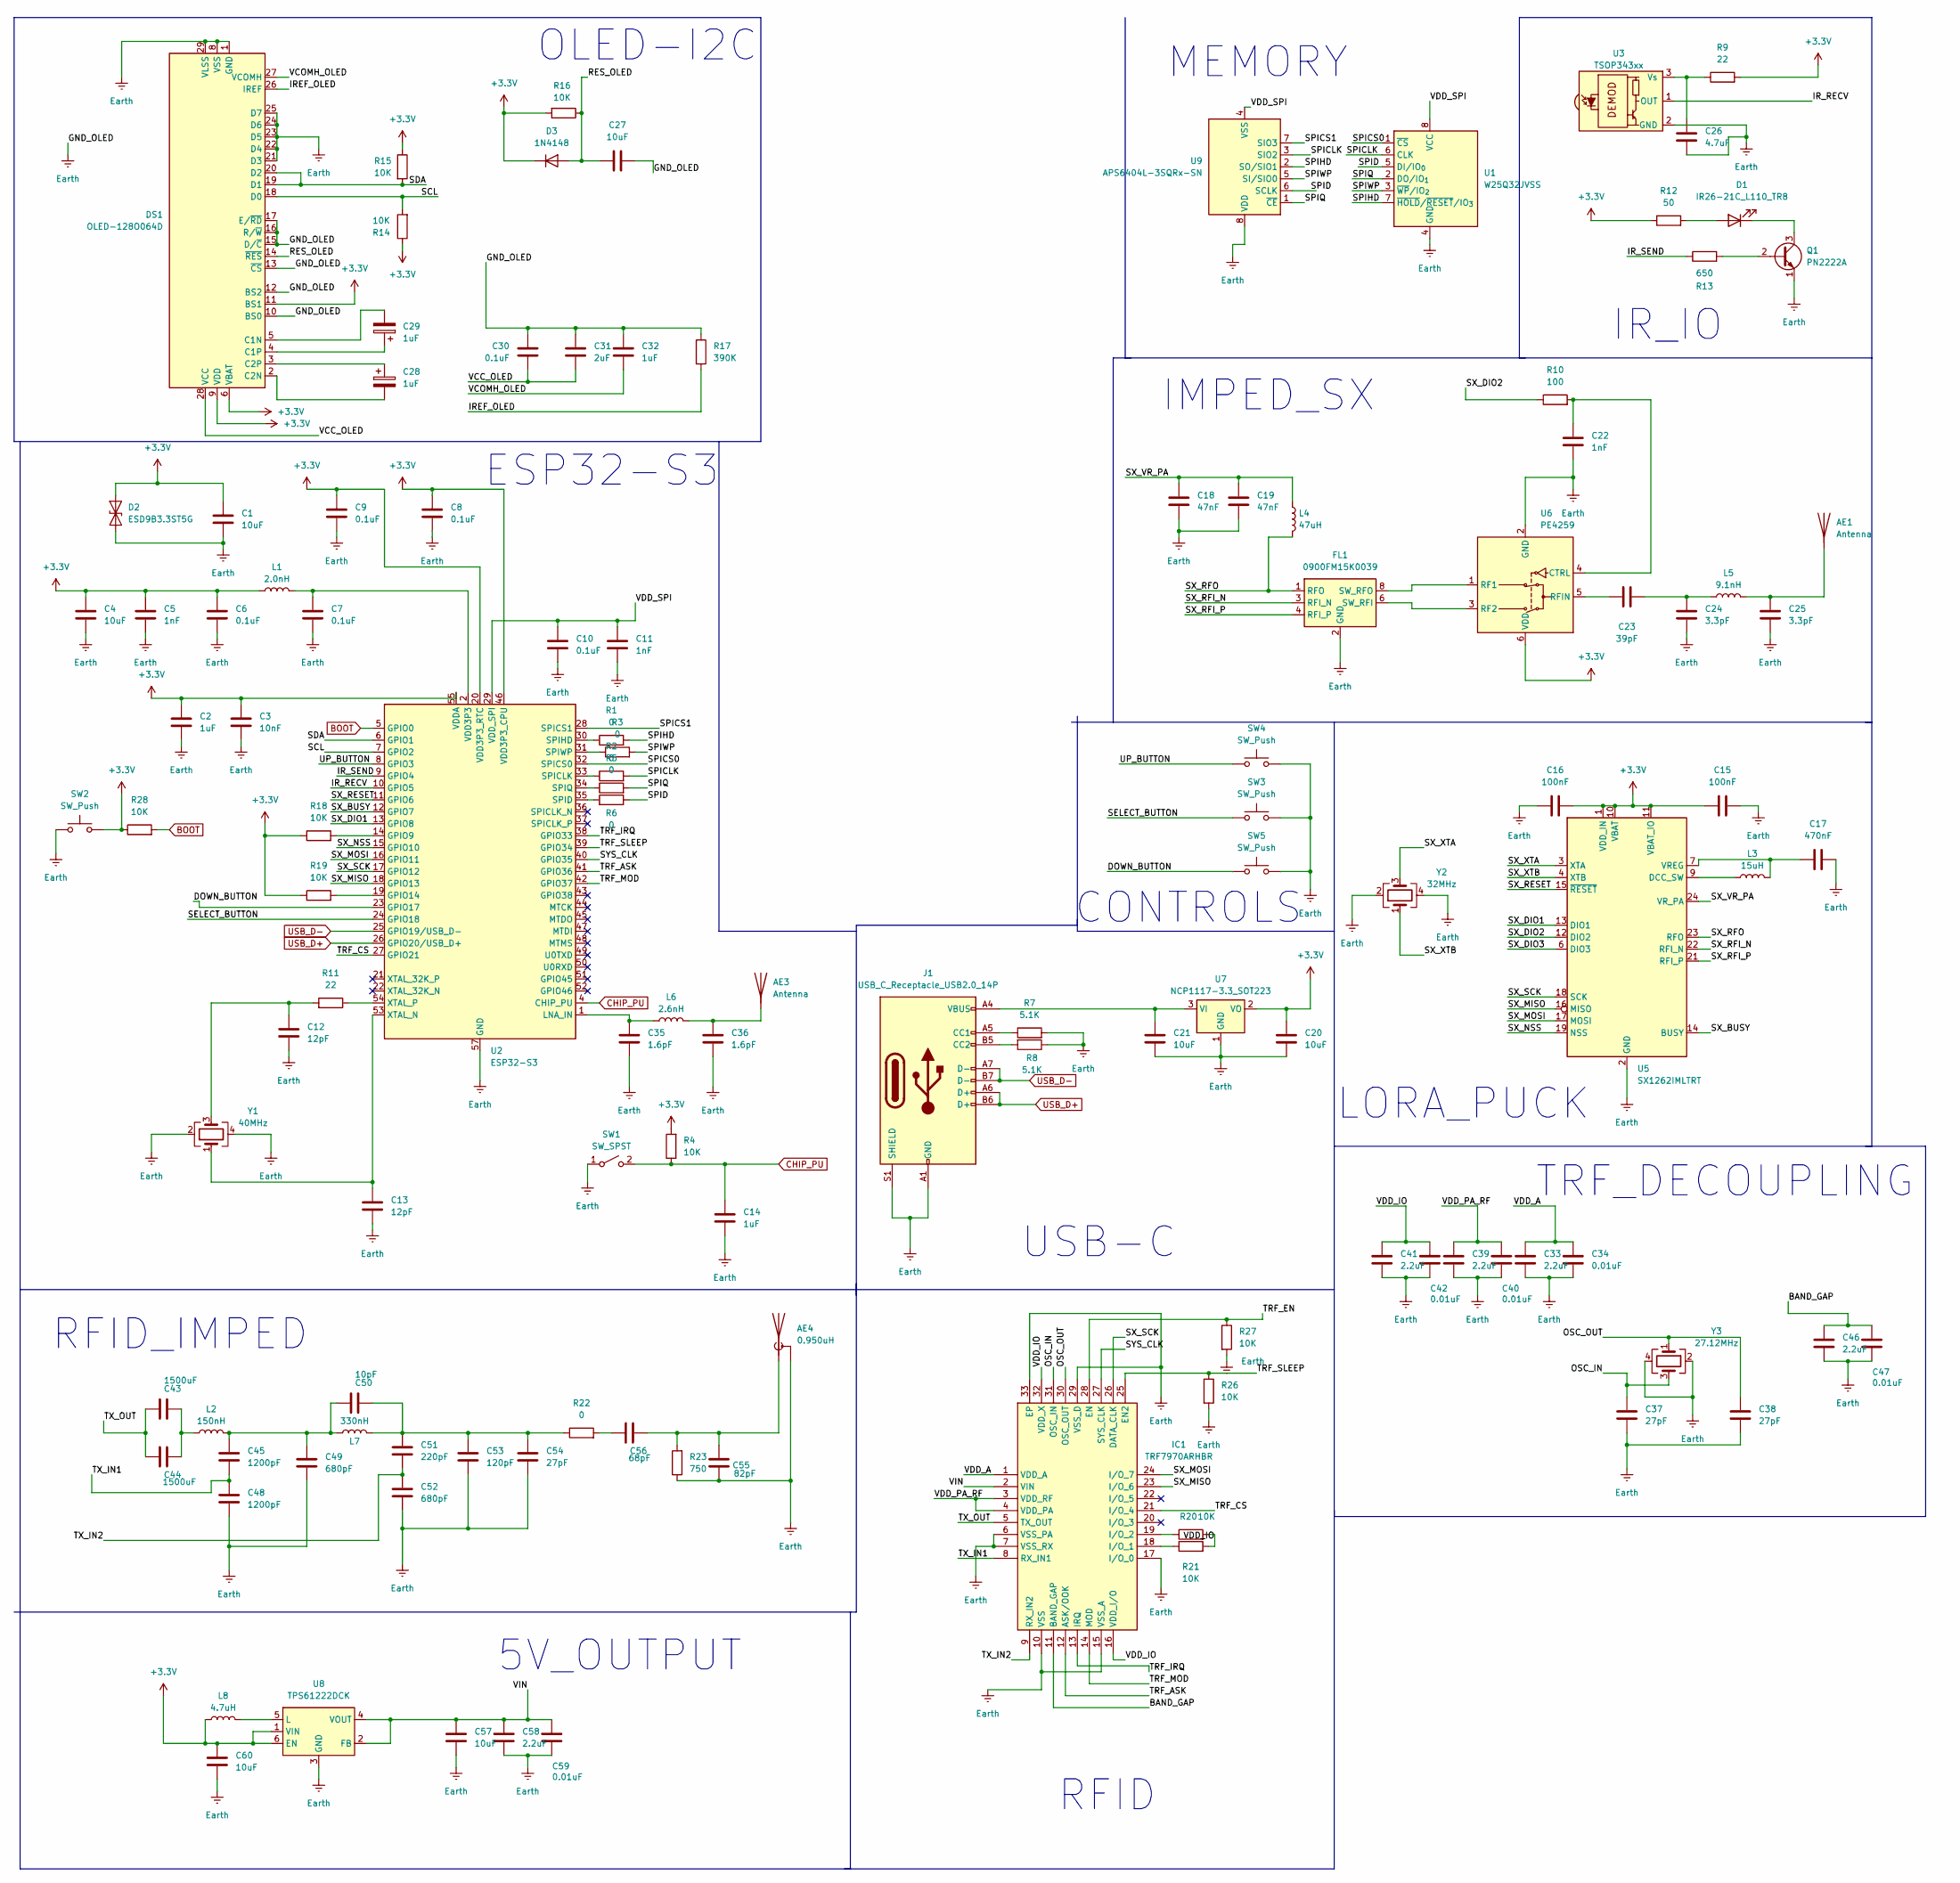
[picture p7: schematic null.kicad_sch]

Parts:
AE1: Antenna; PinSocket_1x01_P2.54mm_Vertical
AE3: Antenna; Molex_47948-0001_2.4Ghz
AE4: 0.950uH; Coilcraft_MA5532-AE_RFID
C1, C4, C20, C21, C60: 10uF; C_0805_2012Metric
C2, C14, C28, C29, C32: 1uF; C_0402_1005Metric
C3: 10nF; C_0805_2012Metric
C5, C11, C22: 1nF; C_0402_1005Metric
C6, C7, C8, C9, C10, C30: 0.1uF; C_0402_1005Metric
C12, C13: 12pF; C_0402_1005Metric
C15, C16: 100nF; C_0402_1005Metric
C17: 470nF; C_0402_1005Metric
C18, C19: 47nF; C_0402_1005Metric
C23: 39pF; C_0402_1005Metric
C24, C25: 3.3pF; C_0402_1005Metric
C26: 4.7uF; C_0402_1005Metric
C27, C57: 10uF; C_0402_1005Metric
C31: 2uF; C_0402_1005Metric
C33, C39, C41, C46, C58: 2.2uF; C_0402_1005Metric
C34, C40, C42, C47, C59: 0.01uF; C_0402_1005Metric
C35, C36: 1.6pF; C_0402_1005Metric
C37, C38, C54: 27pF; C_0402_1005Metric
C43, C44: 1500uF; C_0402_1005Metric
C45, C48: 1200pF; C_0402_1005Metric
C49, C52: 680pF; C_0402_1005Metric
C50: 10pF; C_0402_1005Metric
C51: 220pF; C_0402_1005Metric
C53: 120pF; C_0402_1005Metric
C55: 82pF; C_0402_1005Metric
C56: 68pF; C_0402_1005Metric
D1: IR26-21C_L110_TR8; LED_1206_3216Metric
D2: ESD9B3.3ST5G; D_SOD-923
D3: 1N4148; D_DO-35_SOD27_P7.62mm_Horizontal
DS1: OLED-128O064D
FL1: 0900FM15K0039; Balun_Johanson_0900FM15K0039
IC1: TRF7970ARHBR; QFN50P500X500X100-33N-D; Mouser Part Number 595-TRF7970ARHBR
J1: USB_C_Receptacle_USB2.0_14P; USB_C_Receptacle_HCTL_HC-TYPE-C-16P-01A
L1: 2.0nH; L_0402_1005Metric
L2: 150nH; L_0402_1005Metric
L3: 15uH; L_0402_1005Metric
L4: 47uH; L_0402_1005Metric
L5: 9.1nH; L_0402_1005Metric
L6: 2.6nH; L_0402_1005Metric
L7: 330nH; L_0402_1005Metric
L8: 4.7uH; L_0402_1005Metric
Q1: PN2222A; TO-92_Inline
R1, R2, R3, R5, R6, R22: 0; R_0402_1005Metric
R4, R14, R15, R16, R18, R19, R20, R21, R26, R27, R28: 10K; R_0402_1005Metric
R7, R8: 5.1K; R_0402_1005Metric
R9, R11: 22; R_0402_1005Metric
R10: 100; R_0402_1005Metric
R12: 50; R_0402_1005Metric
R13: 650; R_0402_1005Metric
R17: 390K; R_0402_1005Metric
R23: 750; R_0402_1005Metric
SW1: SW_SPST; SW_SPST_SKQG_WithStem
SW2, SW3, SW4, SW5: SW_Push; SW_Tactile_SPST_NO_Straight_CK_PTS636Sx25SMTRLFS
U1: W25Q32JVSS; SOIC-8_5.3x5.3mm_P1.27mm
U2: ESP32-S3; QFN-56-1EP_7x7mm_P0.4mm_EP4x4mm
U3: TSOP343xx; Vishay_MOLD-3Pin
U5: SX1262IMLTRT; QFN-24-1EP_4x4mm_P0.5mm_EP2.6x2.6mm
U6: PE4259; SOT-363_SC-70-6
U7: NCP1117-3.3_SOT223; SOT-223-3_TabPin2
U8: TPS61222DCK; Texas_R-PDSO-G6
U9: APS6404L-3SQRx-SN; SOIC-8_3.9x4.9mm_P1.27mm
Y1: 40MHz; Crystal_SMD_3225-4Pin_3.2x2.5mm
Y2: 32MHz; Crystal_SMD_3225-4Pin_3.2x2.5mm
Y3: 27.12MHz; Crystal_SMD_3225-4Pin_3.2x2.5mm

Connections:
+3.3V: C1.1, C2.1, C3.1, C4.1, C5.1, C6.1, C8.1, C9.1, C15.2, C16.1, C20.1, C60.1, D2.2 (A2), D3.1 (K), DS1.6 (VBAT), DS1.9 (VDD), DS1.11 (BS1), L1.1, L8.1, R4.2, R9.2, R12.1, R14.1, R15.1, R16.2, R18.1, R19.1, R28.1, SW2.1, U2.20 (VDD3P3_RTC), U2.46 (VDD3P3_CPU), U2.55 (VDDA), U2.56 (VDDA), U5.1 (VDD_IN), U5.10 (VBAT), U5.11 (VBAT_IO), U6.6 (VDD), U7.2 (VO), U8.1 (VIN), U8.6 (EN)
/BAND_GAP: C46.1, C47.1, IC1.11 (BAND_GAP)
/DOWN_BUTTON: SW5.1, U2.23 (GPIO17)
/IREF_OLED: DS1.26 (IREF), R17.2
/IR_RECV: U2.10 (GPIO5), U3.1 (OUT)
/IR_SEND: R13.1, U2.9 (GPIO4)
/OSC_IN: C37.1, IC1.31 (OSC_IN), Y3.3
/OSC_OUT: C38.1, IC1.30 (OSC_OUT), Y3.1
/RES_OLED: C27.1, D3.2 (A), DS1.14 (~RES), R16.1
/SCL: DS1.18 (D0), R14.2, U2.7 (GPIO2)
/SDA: DS1.19 (D1), DS1.20 (D2), R15.2, U2.6 (GPIO1)
/SELECT_BUTTON: SW3.2, U2.24 (GPIO18)
/SPICLK: R2.2, U1.6 (CLK), U9.3 (SIO2)
/SPICS0: U1.1 (~CS), U2.32 (SPICS0)
/SPICS1: U2.28 (SPICS1), U9.7 (SIO3)
/SPID: R6.1, U1.5 (DI/IO_{0}), U9.6 (SCLK)
/SPIHD: R1.2, U1.7 (~HOLD/~RESET/IO_{3}), U9.2 (SO/SIO1)
/SPIQ: R5.2, U1.2 (DO/IO_{1}), U9.1 (~CE)
/SPIWP: R3.2, U1.3 (~WP/IO_{2}), U9.5 (SI/SIO0)
/SX_BUSY: U2.12 (GPIO7), U5.14 (BUSY)
/SX_DIO1: U2.13 (GPIO8), U5.13 (DIO1)
/SX_DIO2: R10.1, U5.12 (DIO2)
/SX_DIO3: U5.6 (DIO3)
/SX_MISO: IC1.23 (I/O_6), U2.18 (GPIO13), U5.16 (MISO)
/SX_MOSI: IC1.24 (I/O_7), U2.16 (GPIO11), U5.17 (MOSI)
/SX_NSS: U2.15 (GPIO10), U5.19 (NSS)
/SX_RESET: U2.11 (GPIO6), U5.15 (~RESET)
/SX_RFI_N: FL1.3 (RFI_N), U5.22 (RFI_N)
/SX_RFI_P: FL1.4 (RFI_P), U5.21 (RFI_P)
/SX_RFO: FL1.1 (RFO), L4.2, U5.23 (RFO)
/SX_SCK: IC1.26 (DATA_CLK), U2.17 (GPIO12), U5.18 (SCK)
/SX_VR_PA: C18.1, C19.1, L4.1, U5.24 (VR_PA)
/SX_XTA: U5.3 (XTA), Y2.3
/SX_XTB: U5.4 (XTB), Y2.1
/SYS_CLK: IC1.27 (SYS_CLK), U2.40 (GPIO35)
/TRF_ASK: IC1.12 (ASK/OOK), U2.41 (GPIO36)
/TRF_CS: IC1.21 (I/O_4), U2.27 (GPIO21)
/TRF_EN: IC1.28 (EN), R27.1
/TRF_IRQ: IC1.13 (IRQ), U2.38 (GPIO33)
/TRF_MOD: IC1.14 (MOD), U2.42 (GPIO37)
/TRF_SLEEP: IC1.25 (EN2), R26.1, U2.39 (GPIO34)
/TX_IN1: C45.2, C48.1, IC1.8 (RX_IN1)
/TX_IN2: C51.2, C52.1, IC1.9 (RX_IN2)
/TX_OUT: C43.2, C44.2, IC1.5 (TX_OUT)
/UP_BUTTON: SW4.1, U2.8 (GPIO3)
/VCC_OLED: C30.2, C31.2, DS1.28 (VCC)
/VCOMH_OLED: C32.2, DS1.27 (VCOMH)
/VDD_A: C33.1, C34.1, IC1.1 (VDD_A)
/VDD_IO: C41.1, C42.1, IC1.16 (VDD_I/O), IC1.32 (VDD_X), R20.2, R21.2
/VDD_PA_RF: C39.1, C40.1, IC1.3 (VDD_RF), IC1.4 (VDD_PA)
/VDD_SPI: C10.1, C11.1, U1.8 (VCC), U2.29 (VDD_SPI), U9.4 (VSS)
/VIN: C57.1, C58.1, C59.1, IC1.2 (VIN), U8.2 (FB), U8.4 (VOUT)
BOOT: R28.2, U2.5 (GPIO0)
CHIP_PU: C14.1, R4.1, SW1.2 (B), U2.4 (CHIP_PU)
Earth: AE4.2 (Shield), C1.2, C2.2, C3.2, C4.2, C5.2, C6.2, C7.2, C8.2, C9.2, C10.2, C11.2, C12.2, C13.2, C14.2, C15.1, C16.2, C17.2, C18.2, C19.2, C20.2, C21.2, C22.2, C24.2, C25.2, C26.2, C27.2, C30.1, C31.1, C32.1, C33.2, C34.2, C35.2, C36.2, C37.2, C38.2, C39.2, C40.2, C41.2, C42.2, C46.2, C47.2, C48.2, C49.2, C52.2, C53.2, C54.2, C55.2, C57.2, C58.2, C59.2, C60.2, D2.1 (A1), DS1.1 (GND), DS1.8 (VSS), DS1.10 (BS0), DS1.12 (BS2), DS1.13 (~CS), DS1.15 (D/~C), DS1.16 (R/~W), DS1.17 (E/~RD), DS1.21 (D3), DS1.22 (D4), DS1.23 (D5), DS1.24 (D6), DS1.25 (D7), DS1.29 (VLSS), DS1.30 (GND), FL1.2 (GND), FL1.5 (GND), FL1.7 (GND), FL1.9 (GND), FL1.10 (GND), IC1.6 (VSS_PA), IC1.7 (VSS_RX), IC1.10 (VSS), IC1.15 (VSS_A), IC1.17 (I/O_0), IC1.29 (VSS_D), IC1.33 (EP), J1.A1 (GND), J1.A12 (GND), J1.B1 (GND), J1.B12 (GND), J1.S1 (SHIELD), Q1.1 (E), R7.2, R8.1, R17.1, R23.1, R26.2, R27.2, SW1.1 (A), SW2.2, SW3.1, SW4.2, SW5.2, U1.4 (GND), U2.57 (GND), U3.2 (GND), U5.2 (GND), U5.5 (GND), U5.8 (GND), U5.20 (GND), U5.25 (GND), U6.2 (GND), U7.1 (GND), U8.3 (GND), U9.8 (VDD), Y1.2, Y1.4, Y2.2, Y2.4, Y3.2, Y3.4
unnamed: AE1.1 (A), C25.1, L5.2
unnamed: AE3.1 (A), C36.1, L6.2
unnamed: AE4.1 (A), C55.1, C56.1, R23.2
unnamed: C7.1, L1.2, U2.2 (VDD3P3), U2.3 (VDD3P3)
unnamed: C12.1, R11.2, Y1.3
unnamed: C23.2, C24.1, L5.1
unnamed: C43.1, C44.1, L2.1
unnamed: C45.1, C49.1, C50.2, L2.2, L7.1
unnamed: C50.1, C51.1, C53.1, C54.1, L7.2, R22.1
unnamed: C56.2, R22.2
unnamed: D1.2 (A), R12.2
unnamed: D1.1 (K), Q1.3 (C)
unnamed: C29.2, DS1.5 (C1N)
unnamed: C29.1, DS1.4 (C1P)
unnamed: C28.2, DS1.2 (C2N)
unnamed: C28.1, DS1.3 (C2P)
unnamed: FL1.6 (SW_RFI), U6.3 (RF2)
unnamed: FL1.8 (SW_RFO), U6.1 (RF1)
unnamed: IC1.18 (I/O_1), R21.1
unnamed: IC1.19 (I/O_2), R20.1
unnamed: J1.A5 (CC1), R7.1
unnamed: J1.B5 (CC2), R8.2
unnamed: Q1.2 (B), R13.2
unnamed: R18.2, U2.14 (GPIO9)
unnamed: R19.2, U2.19 (GPIO14)
unnamed: C35.1, L6.1, U2.1 (LNA_IN)
unnamed: R2.1, U2.33 (SPICLK)
unnamed: R6.2, U2.35 (SPID)
unnamed: R1.1, U2.30 (SPIHD)
unnamed: R5.1, U2.34 (SPIQ)
unnamed: R3.1, U2.31 (SPIWP)
unnamed: C13.1, U2.53 (XTAL_N), Y1.1
unnamed: R11.1, U2.54 (XTAL_P)
unnamed: C26.1, R9.1, U3.3 (Vs)
unnamed: L3.1, U5.9 (DCC_SW)
unnamed: C17.1, L3.2, U5.7 (VREG)
unnamed: C22.1, R10.2, U6.4 (CTRL)
unnamed: C23.1, U6.5 (RFIN)
unnamed: C21.1, J1.A4 (VBUS), J1.A9 (VBUS), J1.B4 (VBUS), J1.B9 (VBUS), U7.3 (VI)
unnamed: L8.2, U8.5 (L)
USB_D+: J1.A6 (D+), J1.B6 (D+), U2.26 (GPIO20/USB_D+)
USB_D-: J1.A7 (D-), J1.B7 (D-), U2.25 (GPIO19/USB_D-)

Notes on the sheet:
TRF_DECOUPLING
MEMORY
LORA_PUCK
5V_OUTPUT
CONTROLS
RFID_IMPED
OLED-I2C
RFID
IR_IO
ESP32-S3
IMPED_SX
USB-C

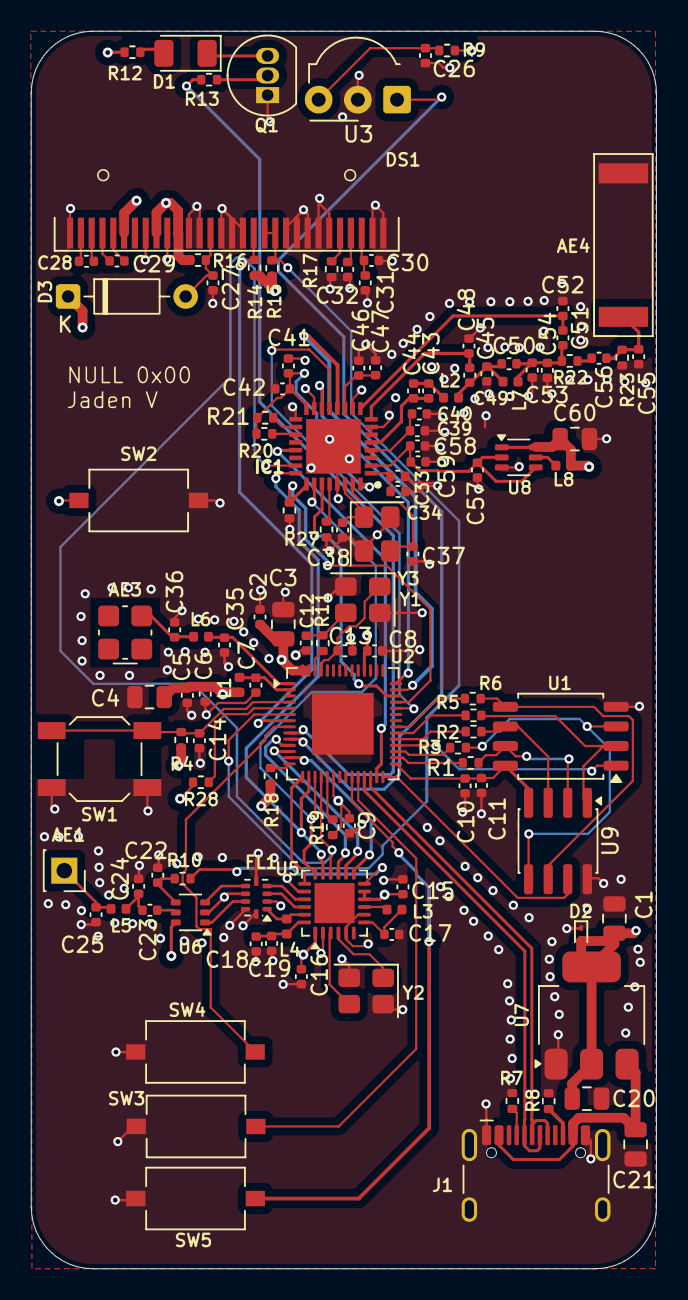
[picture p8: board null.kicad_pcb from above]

Board: 4 copper layers, 40.5 x 80.2 mm, 121 parts (0 on the bottom side), 96 nets.

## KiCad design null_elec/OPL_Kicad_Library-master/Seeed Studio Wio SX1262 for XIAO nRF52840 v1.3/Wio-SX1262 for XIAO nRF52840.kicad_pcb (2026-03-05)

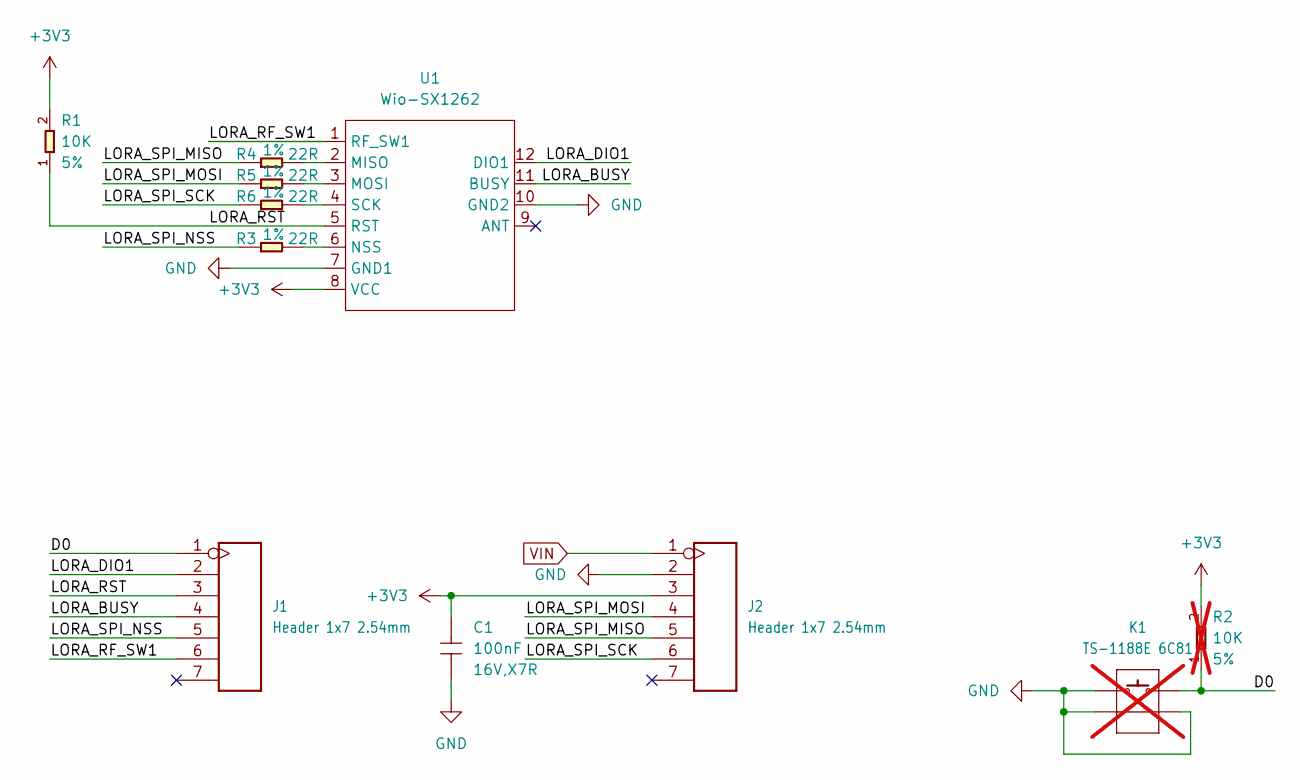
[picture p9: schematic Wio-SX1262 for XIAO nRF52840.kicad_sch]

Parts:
C1: 100nF; C0402; Voltage Rating 16V,X7R; MPN CC0402KRX7R7BB104
J1, J2: Header 1x7 2.54mm; H7-2.54; Part Type Header
K1: TS-1188E 6C81; SW4-SMD-7.0X3.5X3.5MM-90D; MPN TS-1188E 6C81; not fitted
R1: 10K; R0402; Power Rating 5%; MPN RC0402JR-0710KL
R2: 10K; R0402; Power Rating 5%; MPN RC0402JR-0710KL; not fitted
R3, R4, R5, R6: 22R; R0402; Power Rating 1%; MPN RC0402FR-0722RL
U1: Wio-SX1262; MODULE12P-1.27-11X11.6MM; MPN Wio-SX1262

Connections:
+3V3: C1.1, J2.3, R1.2, R2.2, U1.8 (VCC)
/D0: J1.1, K1.2, R2.1
/LORA_BUSY: J1.4, U1.11 (BUSY)
/LORA_DIO1: J1.2, U1.12 (DIO1)
/LORA_RF_SW1: J1.6, U1.1 (RF_SW1)
/LORA_RST: J1.3, R1.1, U1.5 (RST)
/LORA_SPI_MISO: J2.5, R4.1
/LORA_SPI_MOSI: J2.4, R5.1
/LORA_SPI_NSS: J1.5, R3.1
/LORA_SPI_SCK: J2.6, R6.1
GND: C1.2, J2.2, K1.1, K1.3 (S1), K1.4 (S2), U1.7 (GND1), U1.10 (GND2)
unnamed: R4.2, U1.2 (MISO)
unnamed: R5.2, U1.3 (MOSI)
unnamed: R3.2, U1.6 (NSS)
unnamed: R6.2, U1.4 (SCK)
VIN: J2.1

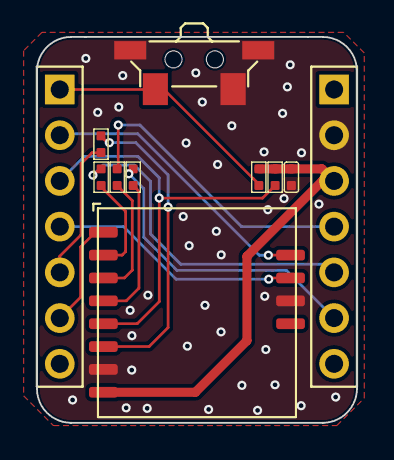
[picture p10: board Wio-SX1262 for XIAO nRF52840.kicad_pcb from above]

Board: 2 copper layers, 17.8 x 21.4 mm, 11 parts (0 on the bottom side), 15 nets.

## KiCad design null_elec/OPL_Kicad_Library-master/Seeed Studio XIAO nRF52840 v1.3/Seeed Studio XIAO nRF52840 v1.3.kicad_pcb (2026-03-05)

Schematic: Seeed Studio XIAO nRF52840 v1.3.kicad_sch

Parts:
ANT1: ANTENNA-AN3216; ANT-SMD3P-3.2X1.6X1.04MM
BAT0: TEST-POINT'4080'; TP-80X40MIL
C1, C5, C8, C24, C34: 100nF; C0201
C2, C7: 10pF; C0201
C3, C4, C6, C9, C22, C25, C29, C30, C39, C41, C42: 2.2uF; C0201
C10: 1nF; C0402
C11: 1pF; C0201
C31: 820pF; C0201
C32, C33: 15pF; C0201
C35: 100pF; C0201
C36: 0.8pF; C0201
C37: 0.5pF; C0201
C38: 4.7nH; L0201
C40: DNP; C0201
CHG0: RED; LED-0402
D1: DIODE'0603'; SOD-523
GND0: GND; TP-80X40MIL
J1, J2: DNP; H7-HALF-HOLE-2.54
K1: BUTTON-4P; SW4-SMD-2.8-2.6X1.6X0.53MM
L3: 10uH; L0603
MIC1: MSM261D3526H1CPM; MIC6P-3.5X2.65X0.94MM
NFC1, NFC2: TEST-POINT'4080'; TP-80X40MIL
Q1: PMOS_1.00.60.35MM; PMOS_1.0_0.6_0.35MM
R1, R2: 5.1k; R0201
R3, R5, R7: 2.2k; R0201
R4, R13, R14, R15, R20: 10k; R0201
R9: 100k; R0201
R10, R11: 33R; R0201
R12, R18: 2.7k; R0201
R16: 1M_1%; R0201
R17: 510k_1%; R0201
RGB6: RGB; 4P1010
TP1, TP2, TP3, TP5: TEST-POINT'4545'; TP-D45MIL
U1: NRF52840_QF; AQFN50P700X700X85_HS-74N
U2: BQ25100; BQ25101_DSBGA_6_BQ25101
U3: LSM6DS3TR-C; LGA14-0.5-2.5X3X0.86MM
U6: 3.3V; X2SON-4
U7: DNP; USON2X3_8
USB1: USB2.0-TYPE-C
X1: 32.768KHz; X2-SMD-L1.6X1.0X0.5MM
X2: 32MHz; 4P1612

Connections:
3V3: C3.2, C6.2, C29.2, C39.1, C41.2, J1.5, J1.17 (5), R5.1, R13.1, RGB6.+, U1.A22 (VDD@A22), U1.AD14 (VDD@AD14), U1.AD23 (VDD@AD23), U1.B1 (VDD@B1), U1.W1 (VDD@W1), U1.Y2 (VDDH@Y2), U6.1 (OUT), U7.8 (VCC)
6D_INT1: U1.T2 (P0.11@T2), U3.4 (INT1)
6D_PWR: C1.2, R14.1, R15.1, U1.P2 (P1.08@P2), U3.5 (VDDIO), U3.8 (VDD), U3.12 (CS)
/CE: R20.1, U2.B1 (TS)
DEC4-6: C34.1, C42.1, L3.2, U1.B5 (DEC4@B5), U1.E24 (DEC6@E24)
GND: ANT1.2 (GND), C1.1, C2.1, C3.1, C4.2, C5.2, C6.1, C7.1, C8.1, C9.1, C10.2, C11.1, C22.1, C24.1, C25.1, C29.1, C30.2, C31.2, C32.2, C33.2, C34.2, C35.2, C36.1, C37.1, C39.2, C40.2, C41.1, C42.2, GND0.1, J1.6, J1.18 (6), K1.2 (B0), K1.4 (B1), MIC1.4 (GND@1), MIC1.5 (L/R), MIC1.6 (GND@2), R1.2, R2.1, R9.1, R18.2, R20.2, TP1.T, U1.B7 (VSS@B7), U1.F23 (VSS_PA@F23), U1.G74 (VSS_PAD), U2.C2 (VSS), U3.1 (SDO/DA0), U3.2 (SDX), U3.3 (SCX), U3.6 (GND@1), U3.7 (GND@2), U6.2 (GND), U6.T (GND), U7.4 (GND), U7.PAD (T), USB1.A1_B12 (A1/B12/GND), USB1.B1_A12 (B1/A12/GND), USB1.S1, USB1.S2, USB1.S3, USB1.S4, USB1.S5 (S1), USB1.S6 (S2), X2.2 (1), X2.4 (3)
INTERNAL_I2C_SCL: R14.2, U1.H2 (P0.27@H2), U3.13 (SCL)
INTERNAL_I2C_SDA: R15.2, U1.M2 (P0.07@M2), U3.14 (SDA)
unnamed: R1.1, USB1.A5 (A5/CC1)
unnamed: R2.2, USB1.B5 (B5/CC2)
unnamed: C2.2, U1.D2 (P0.00/XL1@D2), X1.2
unnamed: C7.2, U1.F2 (P0.01/XL2@F2), X1.1
unnamed: R7.1, RGB6.R-
unnamed: R4.1, RGB6.G-
unnamed: R10.2, U1.AD4 (D-@AD4)
unnamed: R11.2, U1.AD6 (D+@AD6)
unnamed: R3.1, RGB6.B-
unnamed: CHG0.+, R5.2
unnamed: ANT1.3, C10.1
unnamed: R12.1, R18.1, U2.B2 (ISET)
unnamed: C22.2, U1.AC5 (DECUSB@AC5)
unnamed: C24.2, U1.C1 (DEC1@C1)
unnamed: C31.1, U1.N24 (DEC5@N24)
unnamed: C33.1, U1.B24 (XC1@B24), X2.1 (2)
unnamed: C32.1, U1.A23 (XC2@A23), X2.3 (4)
unnamed: C35.1, U1.D23 (DEC3@D23)
unnamed: C36.2, C38.1, U1.H23 (ANT@H23)
unnamed: ANT1.1 (S), C37.2, C38.2
unnamed: C40.1, U1.A18 (DEC2@A18)
unnamed: L3.1, U1.B3 (DCC@B3)
P0.02_AIN0_LOW_A0_D0: J2.1, J2.13 (1), U1.A12 (P0.02/AIN0@A12)
P0.03_AIN1_LOW_A1_D1: J2.2, J2.14 (2), U1.B13 (P0.03/AIN1@B13)
P0.04_AIN2_A4_D4: J2.5, J2.17 (5), U1.J1 (P0.04/AIN2@J1)
P0.05_AIN3_A5_D5: J2.6, J2.18 (6), U1.K2 (P0.05/AIN3@K2)
P0.06_USER_BLUE: R3.2, U1.L1 (P0.06@L1)
P0.09/NFC1: NFC1.1, U1.L24 (P0.09/NFC1@L24)
P0.10/NFC2: NFC2.1, U1.J24 (P0.10/NFC2@J24)
P0.13_HICHG: R12.2, U1.AD8 (P0.13@AD8)
P0.14_~READ_BAT: R17.2, U1.AC9 (P0.14@AC9)
P0.16_PDM_DATA: MIC1.3 (DATA), U1.AC11 (P0.16@AC11)
P0.17_~CHG: CHG0.-, U1.AD12 (P0.17@AD12), U2.C1 (PRETERM)
P0.20_QSPI_SIO_0: U1.AD16 (P0.20@AD16), U7.5 (DI)
P0.21_QSPI_SCK: C11.2, U1.AC17 (P0.21@AC17), U7.6 (CLK)
P0.22_QSPI_SIO_2: U1.AD18 (P0.22@AD18), U7.3 (~WP)
P0.23_QSPI_SIO_3: U1.AC19 (P0.23@AC19), U7.7 (~HOLD)
P0.24_QSPI_SIO_1: U1.AD20 (P0.24@AD20), U7.2 (DO)
P0.25_QSPI_CSN: U1.AC21 (P0.25@AC21), U7.1 (~CS)
P0.26_USER_RED: R7.2, U1.G1 (P0.26@G1)
P0.28_AIN4_LOW_A2_D2: J2.3, J2.15 (3), U1.B11 (P0.28/AIN4@B11)
P0.29_AIN5_LOW_A3_D3: J2.4, J2.16 (4), U1.A10 (P0.29/AIN5@A10)
P0.30_USER_GREEN: R4.2, U1.B9 (P0.30/AIN6@B9)
P0.31_AIN7_BAT: R16.2, R17.1, U1.A8 (P0.31/AIN7@A8)
P1.00_PDM_CLK: MIC1.2 (CLK), U1.AD22 (P1.00@AD22)
P1.10_MIC_PWR: C8.2, MIC1.1 (VDD), U1.A20 (P1.10@A20)
P1.11_TX_D6: J2.7, J2.19 (7), U1.B19 (P1.11@B19)
P1.12_RX_D7: J1.1, J1.13 (1), U1.B17 (P1.12@B17)
P1.13_SCK_D8: J1.2, J1.14 (2), U1.A16 (P1.13@A16)
P1.14_MISO_D9: J1.3, J1.15 (3), U1.B15 (P1.14@B15)
P1.15_MOSI_D10: J1.4, J1.16 (4), U1.A14 (P1.15@A14)
PWR_LED: U1.R24 (P1.06@R24)
RESET: C5.1, K1.1 (A0), K1.3 (A1), R13.2, TP2.T, U1.AC13 (P0.18/RESET@AC13)
SWDCLK: TP3.T, U1.AA24 (SWDCLK@AA24)
SWDIO: TP5.T, U1.AC24 (SWDIO@AC24)
USB_D+: R11.1, USB1.A6 (A6/DP1), USB1.B6 (B6/DP2)
USB_D-: R10.1, USB1.A7 (A7/DN1), USB1.B7 (B7/DN2)
VBAT: BAT0.1, C30.1, Q1.1 (D), R16.1, U2.A1 (OUT)
VBUS: C9.2, C25.2, D1.+, J1.7, J1.19 (7), Q1.2 (G), R9.2, U1.AD2 (VBUS@AD2), U2.A2 (IN), USB1.A4_B9 (A4/B9/VBUS), USB1.B4_A9 (B4/A9/VBUS)
VIN: C4.1, D1.-, Q1.3 (S), U6.3 (EN), U6.4 (IN)

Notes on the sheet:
Linus.Liao
2.Change C32,C33 to 15pF
zhihuai.Zhou
Initail Version
the TS and VSS.
NTC:
2021.2.2
Set P0.14 to output Sink only to enable BAT voltage read;
v1.0
2.Add C11 to to resolve the issue of data corruption during Flash read operations.
1.Change 32M Crystal
Disable Temp sense function,
2025.6.20
1.Remove R8
use fixed 10k resistor between
2024.3.19

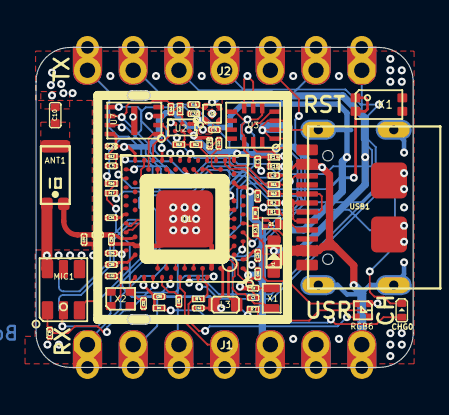
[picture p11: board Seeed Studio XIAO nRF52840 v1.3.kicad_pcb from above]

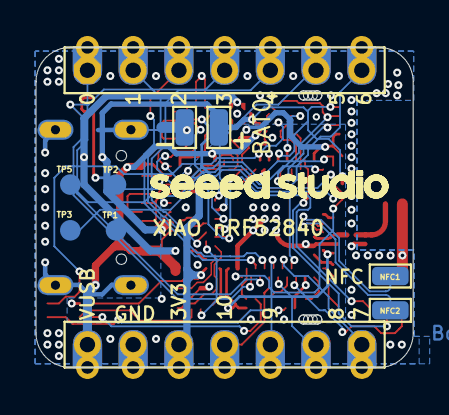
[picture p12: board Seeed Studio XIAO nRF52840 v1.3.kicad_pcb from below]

Board: 2 copper layers, 21.0 x 17.8 mm, 80 parts (9 on the bottom side), 67 nets.

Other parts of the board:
U$14: LOGO-SEEED-NEW-1_3X13MM
UNK_HOLE_0: dummyfp0
UNK_HOLE_1: dummyfp1
UNK_HOLE_2: dummyfp2
UNK_HOLE_3: dummyfp3
UNK_HOLE_4: dummyfp4
UNK_HOLE_5: dummyfp5
UNK_HOLE_6: dummyfp6
UNK_HOLE_7: dummyfp7

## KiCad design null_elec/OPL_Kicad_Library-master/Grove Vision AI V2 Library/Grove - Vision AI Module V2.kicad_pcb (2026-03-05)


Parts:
BOOT1: SW_Push; SW_Push_1P1T_NO_Vertical_Wuerth_434133025816
C1, C2, C17, C18, C19: 1uF; C0402
C3: 10nF; C0402
C4, C6, C7, C9, C10, C28, C34: 4.7uF; C0402
C5, C8, C13, C20, C21, C22, C23, C24, C25, C26, C27, C29, C30, C31, C32, C35, C36, C39: 100nF; C0402
C11, C37: 10uF; C0402
C14, C15: 12pF; C0402
C16: 220nF; C0402
D1, D2, D3, D4: B5819WS; D0805_SOD323
D5, D6, D7, D8: DNP; R0402; MPN DF2S6.8FS
J1: USB_C_Receptacle_USB2.0; USB2.0-TYPE-C
J2: Conn_01x15_MountingPin; FPC_DNC_15P_1.0mm
J3: Conn_01x04_MountingPin; 4P-SMD-2.0mm-RIGHT
J5: ST-TF-MR267; SD-TF-MR267; MPN SD-TF-MR267
L1: VLS201610HBX-4R7M-1; L0806
L2, L3: 470nH; L0603
LED1: Yellow; LED0402
LED2: Green; LED0402
M1: XIAO Connector/DNP; XIAO_Socket
MIC1: MSM261D3526H1CPM; MIC6P-3.5X2.65X0.94MM
Q1, Q2, Q3, Q4, Q5: CJ1012; SOT523
R1, R4, R13, R14, R15, R19, R20, R21, R22, R40: 2.2k; R0402
R2, R3, R36: 5.1k; R0402
R5, R7, R23, R24: 10k; R0402
R6, R16, R32, R33: 100K; R0402; Power Rating 1%; MPN RC0402JR-074K7L
R8, R31, R38: 10K; R0402; Power Rating 5%; MPN RC0402JR-074K7L
R9, R12, R17, R18, R25, R27, R28: DNP; R0402
R10, R11, R37: 100k; R0402
R26, R34: 22K; R0402; Power Rating 1%; MPN RC0402JR-074K7L
R29, R30, R39: 0R; R0402
R35: 510k; R0402
RST1: SW_Push; SW_Push_1P1T_NO_Vertical_Wuerth_434133025816
TP1, TP2, TP3: Test Point; TP-D35MIL; Part Type Test Point
U1: HX6538; WLCSP65_5.6x2.3x0.56mm
U2: CH343P; QFN-16-EP_3x3mm_P0.5mm_EP1x1mm
U3: WR0331-18FF4R; X2SON-4
U4, U6: SY80004DQD; DFN6-0.5-1.5X1.5X0.65MM; MPN SY80004DQD
U5: W25Q128JWSIQ; SOIC-8_5.23x5.23mm_P1.27mm
X1: 24MHz; 4P2016

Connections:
1V8: C13.1, C19.2, C20.1, C21.1, C28.1, C29.2, Q1.1 (G), Q2.1 (G), R5.1, R21.2, R22.2, R25.1, TP2.1 (T), U1.F3 (VDDIO_SIF1), U1.G3 (VDDA_RX), U1.H5 (VDDA_TX), U1.L2 (VDDIO_SIF2), U3.1 (OUT), U5.8 (VCC)
/0V9: C4.1, C7.1, L1.2, U1.L4 (DCDC_OUT)
BOOTOPT0: D3.1 (K), R11.1, U1.F4 (BOOT_OPT)
GND: C1.2, C2.2, C3.2, C4.2, C5.2, C6.2, C7.2, C8.1, C9.2, C10.2, C11.1, C13.2, C14.2, C15.1, C17.2, C18.2, C19.1, C20.2, C21.2, C22.2, C23.2, C24.1, C25.1, C26.2, C27.1, C28.2, C29.1, C30.1, C31.2, C34.2, C35.1, C37.1, C39.1, D5.1, D6.1, D7.1, D8.1, J1.A1_B1_A12_B12 (GND), J1.S1 (SHIELD), J2.1, J2.4, J2.7, J2.10, J2.MP (MountPin), J3.4, J3.MP (MountPin), J5.S1 (SHD1), J5.S2 (SHD2), J5.S3 (SHD3), J5.S4 (SHD4), J5.T6 (VSS), LED2.1 (K), M1.13 (GND), MIC1.4 (GND), MIC1.5 (L/R), MIC1.6 (GND), Q3.2 (S), R2.2, R3.2, R10.2, R11.2, R23.2, R26.1, R34.1, R37.2, RST1.2, TP3.1 (T), U1.C5 (GND1), U1.G4 (GND2), U1.H3 (GND3), U1.L3 (GND4), U1.M2 (GND5), U1.M4 (GND6), U2.2 (GND), U2.17 (EPAD), U3.2 (GND), U3.T (GND), U4.4 (GND), U5.4 (GND), U6.4 (GND), X1.2 (1), X1.4 (3)
GROVE_5V_IN: C18.1, C34.1, C35.2, J3.3, R14.1, R15.1, R31.2, R32.2, U6.6 (IN)
I2CS0_SCL/5V: J3.1, Q4.3 (D), R14.2
I2CS0_SDA/5V: J3.2, Q5.3 (D), R15.2
M_3V3_SCL: J2.13, Q1.3 (D), R19.2
M_3V3_SDA: J2.14, Q2.3 (D), R20.2
unnamed: BOOT1.2, R4.2
unnamed: D1.2 (A), R36.2
unnamed: C9.1, C10.1, C27.2, D2.1 (K), D4.1 (K), R6.2, R8.2, U4.6 (IN)
unnamed: BOOT1.1, D3.2 (A), R36.1
unnamed: J1.A5 (CC1), R2.1
unnamed: J1.B5 (CC2), R3.1
unnamed: LED1.2 (A), R38.1
unnamed: LED1.1 (K), Q3.3 (D)
unnamed: LED2.2 (A), R24.2
unnamed: M1.12 (3V3), R39.2
unnamed: MIC1.2 (CLK), R29.1
unnamed: MIC1.3 (DATA), R30.1
unnamed: Q3.1 (G), R37.1, R40.2
unnamed: R10.1, U1.E4 (TEST_MODE)
unnamed: L1.1, U1.L5 (VX1)
unnamed: C14.1, R35.1, U1.G2 (XTAL_24M_I), X1.3 (4)
unnamed: C15.2, R35.2, U1.F1 (XTAL_24M_O), X1.1 (2)
unnamed: C16.2, U2.13 (RTS)
unnamed: R8.1, U4.1 (EN)
unnamed: C32.1, R16.1, R26.2, U4.3 (FB)
unnamed: L2.1, U4.5 (LX)
unnamed: R6.1, U4.2 (PG)
unnamed: R31.1, U6.1 (EN)
unnamed: C36.1, R33.1, R34.2, U6.3 (FB)
unnamed: L3.1, U6.5 (LX)
unnamed: R32.1, U6.2 (PG)
PA0/3V3: M1.1 (D0/A0), U1.D4 (PA0)
PA1/VMUTE/3V3: J2.11, U1.C4 (PA1)
PA2/I2CS0_SCL/3V3: M1.6 (D5/SCL), Q4.2 (S), R1.1, R17.2, U1.A4 (PA2)
PA3/I2CS0_SDA/3V3: M1.5 (D4/SDA), Q5.2 (S), R13.1, R18.2, U1.B4 (PA3)
PB0/RX0/3V3: U1.A5 (PB0), U2.4 (TXD)
PB1/TX0/3V3: U1.B5 (PB1), U2.5 (RXD)
PB2/SSPIM_DO/3V3: D7.2, J5.T3 (CMD), M1.11 (D10/MOSI), R12.2, U1.N5 (PB2)
PB3/SSPIM_DI/3V3: D5.2, J5.T7 (DAT0), M1.10 (D9/MISO), R9.2, U1.M3 (PB3)
PB4/SSPIM_SCLK/3V3: D6.2, J5.T5 (CLOCK), M1.9 (D8/SCK), R27.2, U1.N4 (PB4)
PB5/SSPIM_~CS/3V3: D8.2, J5.T2 (CD/DAT3), R28.2, U1.N3 (PB5)
PB6/UART1_RX/3V3: M1.7 (D6/TX), U1.N1 (PB6)
PB7/UART1_TX/3V3: M1.8 (D7/RX/SS), U1.M1 (PB7)
PB8/3V3: M1.3 (D2/A2), U1.L1 (PB8)
PB9/PDM_CLK/3V3: R29.2, U1.F5 (PB9)
PB10/PDM_DATA0/3V3: R30.2, U1.G5 (PB10)
PB11/3V3: M1.2 (D1/A1), U1.J3 (PB11)
QSPI_CLK: U1.C2 (QSPI_CLK), U5.6 (CLK)
QSPI_CS: R5.2, U1.B2 (QSPI_CS), U5.1 (~CS)
QSPI_D0: U1.B1 (QSPI_DIO0), U5.5 (DI(IO0))
QSPI_D1: U1.D3 (QSPI_DIO1), U5.2 (DO(IO1))
QSPI_D2: U1.A1 (QSPI_DIO2), U5.3 (IO2)
QSPI_D3: U1.E3 (QSPI_DIO3), U5.7 (IO3)
RST: C3.1, C16.1, M1.4 (D3/A3), R7.1, RST1.1, U1.E5 (RESETN)
RX_CK_N: J2.8, U1.E2 (RX_CKN)
RX_CK_P: J2.9, U1.F2 (RX_CKP)
RX_D0_N: J2.2, U1.D2 (RX_DN0)
RX_D0_P: J2.3, U1.C1 (RX_DP0)
RX_D1_N: J2.5, U1.D1 (RX_DN1)
RX_D1_P: J2.6, U1.E1 (RX_DP1)
SEN_D1/SD~INSERT: J5.G1 (SWITCH), R25.2, U1.G1 (SEN_D1)
SEN_I2CM_SCL: Q1.2 (S), R21.1, U1.A3 (SEN_I2CM_SCL)
SEN_I2CM_SDA: Q2.2 (S), R22.1, U1.B3 (SEN_I2CM_SDA)
UD+: J1.A6 (D+), J1.B6 (D+), U2.7 (D+)
UD-: J1.A7 (D-), J1.B7 (D-), U2.8 (D-)
USER_LED/1V8: R40.1, U1.K2 (SEN_D2)
USR_BTN/1V8: D1.1 (K), R23.1, U1.H1 (SEN_D0)
V33IO: C2.1, C31.1, U2.1 (VIO), U2.6 (V3)
VBUS: C1.1, C30.2, D4.2 (A), J1.A4_B4_A9_B9 (VBUS), U2.3 (VDD5), U2.9 (VBUS)
VCC_3V3: C5.1, C6.1, C8.2, C11.2, C17.1, C22.1, C23.1, C24.2, C25.2, C26.1, C32.2, C36.2, C37.2, C39.2, J2.15, J5.T4 (VDD), L2.2, L3.2, MIC1.1 (VDD), Q4.1 (G), Q5.1 (G), R1.2, R4.1, R7.2, R9.1, R12.1, R13.2, R16.2, R17.1, R18.1, R19.1, R20.1, R24.1, R27.1, R28.1, R33.2, R38.2, R39.1, TP1.1 (T), U1.D5 (VDDIO_AON), U1.M5 (VDDA_DCDC), U1.N2 (VDDIO_PIF), U3.3 (EN), U3.4 (IN)
VMAIN: D2.2 (A), M1.14 (VUSB)

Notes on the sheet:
MIPI CSI
AON 3V3
MIPI DSI
PIF 3V3
SIF only 1V8
Imax=600mA
23/11/14
Grove - Vision AI Module V2
JN.FUONG

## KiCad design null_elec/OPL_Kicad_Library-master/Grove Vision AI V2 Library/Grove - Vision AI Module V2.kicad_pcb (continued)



Board: 4 copper layers, 40.0 x 20.0 mm, 112 parts (31 on the bottom side), 75 nets.

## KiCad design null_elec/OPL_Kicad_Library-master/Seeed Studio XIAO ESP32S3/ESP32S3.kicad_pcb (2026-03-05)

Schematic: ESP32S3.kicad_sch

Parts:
ANT1: U.FL-R-SMT-1; U-FL3P-SMD-2.6X2.6X1.0MM
BAT0: VBAT; TP-80X40MIL
C1, C2, C17, C20: DNP; C0201
C3, C9, C13, C16: 2.2uF; C0201
C4, C5, C6: 4.7uF; C0201
C7, C8, C28: 10pF; C0201
C10, C21, C25, C26: 1uF; C0201
C11, C14, C15, C19, C22, C23, C29, C30: 100nF; C0201
C12: 10nF; C0201
C18: 1pF; C0201
CHG0: RED; LED-0402
D2: LMBR4010BST5G; DFN1006-2L
D3: Yellow; LED-0402
GND0: GND; TP-80X40MIL
J1, J2: DNP; H7-HALF-HOLE-2.54
J3: DF40C-30DP-0.4V(51); BTB30-0.4-7.52X2.97X1.14
K1, K2: SKTAAAE010/311021459; SW4-SMD-2.8-2.6X1.6X0.53MM
L1: 2nH; L0201
L2: 3.3nH; L0201
L3: DNP; L0201
L4: 470nH; L0603
Q1: LP0404N3T5G; PMOS_1.0_0.6_0.35MM
R1, R2: 5.1K; R0201
R3, R4: 22R; R0201
R5: 0R; R0201
R6: 499R; R0201
R7, R8, R11: 10K; R0201
R9: 100K; C0201
R10: 220K; R0201
R13: 249K; R0201
R15: 1.5K; R0201
TP1, TP2, TP3, TP4, TP5, TP6, TP7, TP8: TEST-POINT'4545'; TP-D45MIL
U1: ESP32-S3R8; QFN56G-0.4-7X7MM
U3: SGM6029CYG/TR; BGA6-0.35-0.745X10.95X0.4MM
U4: SGM40567-4.2XG/TR; WLCSP-0.4-0.92X1.16X0.4MM
U5: GD25Q64ENIGR; USON8-0.8-4X3MM
USB0: UBF31-0171; USB2.0-TYPE-C
X1: 40MHz/306011364; X4-SMD-1.6X1.2X0.35MM

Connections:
D0/A0: J2.1, J2.13 (1), U1.6 (GPIO1)
D1/A1: J2.2, J2.14 (2), U1.7 (GPIO2)
D2/A2: J2.3, J2.15 (3), J3.2, U1.8 (GPIO3)
D3/A3: J2.4, J2.16 (4), U1.9 (GPIO4)
D4/I2C_SDA: J2.5, J2.17 (5), U1.10 (GPIO5)
D5/I2C_SCL: J2.6, J2.18 (6), U1.11 (GPIO6)
D6/TX: J2.7, J2.19 (7), R6.2
D7/RX: J1.1, J1.13 (1), U1.50 (U0RXD)
D8/A8/SCK: J1.2, J1.14 (2), J3.3, U1.12 (GPIO7)
D9/A9/MISO: J1.3, J1.15 (3), J3.4, U1.13 (GPIO8)
D10/A10/MOSI: J1.4, J1.16 (4), J3.5, U1.14 (GPIO9)
EN: C21.2, K1.1 (A0), K1.3 (A1), R8.1, TP6.T, U1.4 (CHIP_PU)
ESP_USB_D+: C1.2, R4.2, TP8.T, U1.26 (GPIO20)
ESP_USB_D-: C2.2, R3.2, TP7.T, U1.25 (GPIO19)
GND: ANT1.GND1, ANT1.GND2, C1.1, C2.1, C3.2, C4.2, C5.1, C6.1, C7.2, C8.1, C9.1, C10.2, C11.1, C12.1, C13.1, C14.1, C15.1, C16.1, C17.1, C18.1, C19.1, C20.1, C21.1, C22.1, C23.2, C25.2, C26.2, C28.1, C29.1, C30.1, GND0.1, J1.6, J1.18 (6), J3.1, J3.17, J3.28, J3.29, J3.31, J3.33, J3.34, K1.2 (B0), K1.4 (B1), K2.2 (B0), K2.4 (B1), R1.1, R2.2, R9.1, R10.1, R13.1, TP1.T, U1.57 (GND), U3.A1 (GND), U4.B1 (F), U4.C2 (GND), U5.4 (GND), USB0.A1_B12 (A1/B12/GND), USB0.B1_A12 (B1/A12/GND), USB0.S1, USB0.S2, USB0.S3, USB0.S4, USB0.S5 (S1), USB0.S6 (S2), X1.2 (GND), X1.4 (GND@1)
GND5: L4.1, U3.B2 (SW)
GND6: R13.2, U3.C1 (MODE)
GPIO0: C28.2, K2.1 (A0), K2.3 (A1), R7.1, U1.5 (GPIO0)
IO10/XMCLK: J3.6, U1.15 (GPIO10)
IO11/DVP_Y8: J3.7, U1.16 (GPIO11)
IO12/DVP_Y7: J3.8, U1.17 (GPIO12)
IO13/DVP_PCLK: J3.9, U1.18 (GPIO13)
IO14/DVP_Y6: J3.10, U1.19 (GPIO14)
IO15/DVP_Y2: J3.11, U1.21 (XTAL_32K_P)
IO16/DVP_Y5: J3.12, U1.22 (XTAL_32K_N)
IO17/DVP_Y3: J3.13, U1.23 (GPIO17)
IO18/DVP_Y4: J3.14, U1.24 (GPIO18)
IO21/USER_LED: D3.-, J3.16, U1.27 (GPIO21)
IO38/DVP_VSYNC: J3.23, U1.43 (GPIO38)
IO47/DVP_HREF: J3.22, U1.37 (SPICLK_P)
IO48/DVP_Y9: J3.21, U1.36 (SPICLK_N)
MTCK/IO39/CAM_SCL: J3.24, TP5.T, U1.44 (MTCK)
MTDI/IO41/PDM_DATA: J3.26, TP3.T, U1.47 (MTDI)
MTDO/IO40/CAM_SDA: J3.25, TP4.T, U1.45 (MTDO)
MTMS/IO42/PDM_CLK: J3.27, TP2.T, U1.48 (MTMS)
unnamed: R5.1, U1.54 (XTAL_P)
unnamed: C7.1, R5.2, X1.3 (X2)
unnamed: C8.2, U1.53 (XTAL_N), X1.1 (X1)
unnamed: ANT1.D, C17.2, L2.1, L3.2
unnamed: R2.1, USB0.B5 (B5/CC2)
unnamed: C15.2, L1.2, U1.2 (VDD3P3@1), U1.3 (VDD3P3@2)
unnamed: R1.2, USB0.A5 (A5/CC1)
unnamed: C18.2, L2.2, U1.1 (LNA_IN)
unnamed: CHG0.-, U4.B2 (NCHG)
unnamed: R6.1, U1.49 (U0TXD)
unnamed: R10.2, U4.C1 (IREF)
unnamed: CHG0.+, R11.2
unnamed: D3.+, R15.1
unnamed: C20.2, L3.1
SPICLK: U1.33 (SPICLK), U5.6 (CLK)
SPICS0: U1.32 (SPICS0), U5.1 (/CS)
SPID: U1.35 (SPID), U5.5 (DIO)
SPIHD: U1.30 (SPIHD), U5.7 (/HOLD)
SPIQ: U1.34 (SPIQ), U5.2 (DO)
SPIWP: U1.31 (SPIWP), U5.3 (/WP)
USB_D+: R4.1, USB0.A6 (A6/DP1), USB0.B6 (B6/DP2)
USB_D-: R3.1, USB0.A7 (A7/DN1), USB0.B7 (B7/DN2)
VBAT: BAT0.1, C26.1, Q1.1 (D), U4.A1 (BAT)
VBUS: C10.1, C25.1, D2.+, J1.7, J1.19 (7), Q1.2 (G), R9.2, R11.1, U4.A2 (VIN), USB0.A4_B9 (A4/B9/VBUS), USB0.B4_A9 (B4/A9/VBUS)
VCC_3V3: C5.2, C6.2, C9.2, C11.2, C12.2, C13.2, C14.2, C16.2, C19.2, C23.1, C29.2, J1.5, J1.17 (5), J3.18, J3.19, L1.1, L4.2, R7.2, R8.2, R15.2, U1.20 (VDD3P3_RTC), U1.46 (VDD3P3_CPU), U1.55 (VDDA@1), U1.56 (VDDA@2), U3.A2 (VOS)
VDD_SPI: C22.2, U1.29 (VDD_SPI), U5.8 (VCC)
VIN: C3.1, C4.1, C30.2, D2.-, J3.15, J3.30, Q1.3 (S), U3.B1 (VIN), U3.C2 (EN)

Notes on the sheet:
IO40
IO39
Π Type Impedance Matching
2.Adjust C30 and C16 inward
D0/A0/Qt1
DVP_Y7
Li Battery
IO5
External Flash
Optimize the distance from the positioning hole of the shield to the pads on both sides
DVP_Y3
D10/A10/Qt9/MOSI
0.3A/Pin
2023/1/4
LC Filter
IO1
D1/A1/Qt2
CAM
IO12
ESP32-S3
USB D+
Layout note： Bottom
D9/A9/Qt8/MISO
IO42
S3 IO20/D+
PDM_CLK
LCD
XIAO Header
v1.1
IO47
IO48
IO4
Camera
DVP_Y6
Internal PSRAM
IO21
IO11
BOOT
CAM_SCL
IO10



Board: 2 copper layers, 17.8 x 21.1 mm, 72 parts (11 on the bottom side), 62 nets.

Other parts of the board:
U$7: LOGO-SEEED-NEW-0.94X8.4MM

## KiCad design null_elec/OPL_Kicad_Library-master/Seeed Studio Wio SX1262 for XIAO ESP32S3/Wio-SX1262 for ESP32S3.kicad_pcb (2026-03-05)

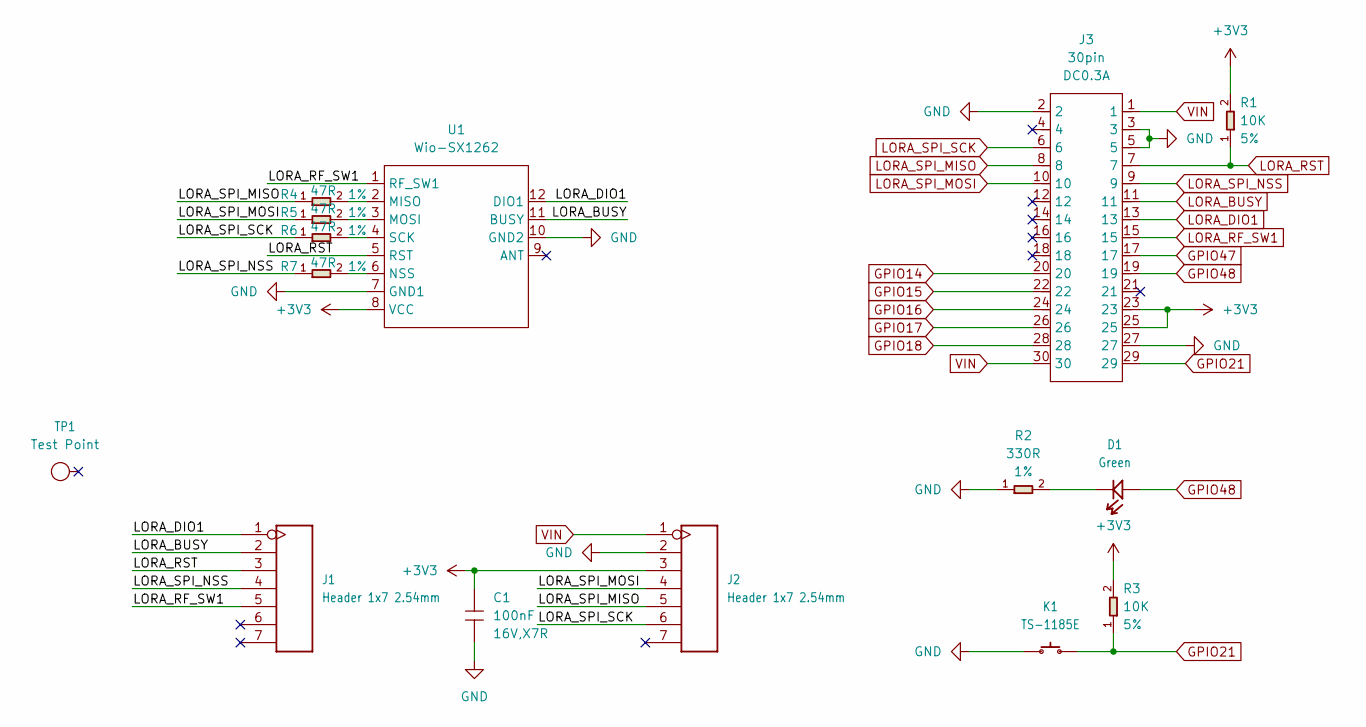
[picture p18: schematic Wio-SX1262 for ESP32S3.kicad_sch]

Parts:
C1: 100nF; C0402; Voltage Rating 16V,X7R; MPN CC0402KRX7R7BB104
D1: Green; LED-0603; MPN 19-217/G7C-AN1P2/3T
J1, J2: Header 1x7 2.54mm; H7-2.54; Part Type Header
J3: 30pin; BTB2X15-FEMALE-8.6X2.94X3.9MM; Rating DC0.3A; MPN BTB SCOKET P0.40
K1: TS-1185E; BUTTON2P_3_9X3X2MM; MPN TS-1185E
R1, R3: 10K; R0402; Power Rating 5%; MPN RC0402JR-0710KL
R2: 330R; R0402; Power Rating 1%; MPN RC0402FR-07330RL
R4, R5, R6, R7: 47R; R0402; Power Rating 1%; MPN RC0201FR-0745RL
TP1: Test Point; TP-D3_5c2_2mm; Part Type Test Point
U1: Wio-SX1262; MODULE12P-1.27-11X11.6MM; MPN Wio-SX1262

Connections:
+3V3: C1.1, J2.3, J3.23, J3.25, R1.2, R3.2, U1.8 (VCC)
GND: C1.2, J2.2, J3.2, J3.3, J3.5, J3.27, K1.1, R2.1, U1.7 (GND1), U1.10 (GND2)
GPIO14: J3.20
GPIO15: J3.22
GPIO16: J3.24
GPIO17: J3.26
GPIO18: J3.28
GPIO21: J3.29, K1.2, R3.1
GPIO47: J3.17
GPIO48: D1.1 (+), J3.19
LORA_BUSY: J1.2, J3.11, U1.11 (BUSY)
LORA_DIO1: J1.1, J3.13, U1.12 (DIO1)
LORA_RF_SW1: J1.5, J3.15, U1.1 (RF_SW1)
LORA_RST: J1.3, J3.7, R1.1, U1.5 (RST)
LORA_SPI_MISO: J2.5, J3.8, R4.1
LORA_SPI_MOSI: J2.4, J3.10, R5.1
LORA_SPI_NSS: J1.4, J3.9, R7.1
LORA_SPI_SCK: J2.6, J3.6, R6.1
unnamed: D1.2 (-), R2.2
unnamed: R4.2, U1.2 (MISO)
unnamed: R5.2, U1.3 (MOSI)
unnamed: R7.2, U1.6 (NSS)
unnamed: R6.2, U1.4 (SCK)
VIN: J2.1, J3.1, J3.30



Board: 2 copper layers, 17.8 x 21.4 mm, 15 parts (5 on the bottom side), 18 nets.

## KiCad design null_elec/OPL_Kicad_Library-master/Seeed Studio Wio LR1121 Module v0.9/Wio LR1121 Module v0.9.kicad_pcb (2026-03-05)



Board: 4 copper layers, 17.0 x 12.0 mm, 69 parts (3 on the bottom side), 47 nets.

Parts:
C1, C2, C3, C4, C5, C6, C7, C8, C9, C11, C12, C13, C14, C15, C18, C19, C20, C22, C24, C25, C26, C27, C28, C29, C30, C31, C32, C33, C34, C35, C36, C37, C38, C39, C40, C41, C42, C43: C0201
FB1: L0201
J1, J2: U-FL4P-SMD-1_7X1_7X1_0MM
L1: L0402
L2, L3, L5, L6, L7, L8, L9, L10, L11, L13: L0201
L12: L0603
OSC1: X4_SMD_2_5X2_0MM
R1, R2, R3, R4, R5, R7, R8, R9: R0201
TP23, TP24, TP25: TP35S_SMD
U1: QFN12_0D5_2X2X0_55MM
U2: QFN32_0D5_5X5MM_EP3P3MM
U3: MODULE24_1D27_17X12MM
X1: X2_SMD_2X1_2MM

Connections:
2.4G_RF: C43.2, U3.2
GND_POWER: C3.2, C4.2, C5.2, C6.2, C7.2, C8.2, C11.2, C12.2, C13.2, C14.2, C15.2, C18.2, C19.2, C22.2, C25.2, C26.2, C28.2, C29.2, C30.2, C31.2, C32.2, C33.2, C35.2, C36.2, C37.2, C38.2, C40.2, C42.2, J1.2, J1.3, J1.4, J2.2, J2.3, J2.4, OSC1.1, OSC1.2, U1.2, U1.7, U1.8, U1.10, U1.12, U1.13, U2.13, U2.33, U3.1, U3.3, U3.9, U3.10, U3.13, U3.15, U3.16, U3.17, U3.18, U3.19, U3.22, U3.24
HP_LF: C1.1, L1.2, L2.1, R1.2, U2.32
LP_LF: C9.1, L6.1, L13.2, U2.31
LR1121_BUSY: U2.25, U3.8
LR1121_DIO8: U2.10, U3.11
LR1121_DIO9_INT: U2.9, U3.12
LR1121_RSTN: C42.1, R7.2, U2.6, U3.14
LR1121_SPI_MISO: U2.21, U3.7
LR1121_SPI_MOSI: U2.22, U3.6
LR1121_SPI_NSS: U2.24, U3.4
LR1121_SPI_SCK: U2.23, U3.5
MCU_DIO5: R3.1, TP23.1, U2.20
MCU_DIO6: R2.1, TP24.1, U2.19
MCU_DIO7: R5.1, TP25.1, U2.11
N18704063: C25.1, U2.7, X1.1
N18704080: C26.1, U2.8, X1.2
N18704168: L12.2, U2.14
N18704177: C31.1, L12.1, U2.12
N18704981: C9.2, C37.1, L6.2, L7.1
N18704990: C1.2, C3.1, L2.2, L3.1
N18705097: C2.1, C4.1, L3.2
N18705182: C38.1, C39.1, L7.2
N18705449: C18.1, C39.2, U1.3
N18705460: C2.2, C5.1, U1.1
N18706098: C20.2, C40.1, C41.1, L9.2
N18706198: C41.2, U1.9
N18706539: C24.1, C29.1, L10.2, L11.1
N18706650: C24.2, C27.1, C30.1, C43.1, L11.2
N18706671: C27.2, J2.1
N18712116: C14.1, L5.1, U1.11
N18712319: C36.1, FB1.2, OSC1.4
N18712325: C34.1, OSC1.3
N18712327: C34.2, R4.1
N18713044: C15.1, L5.2, R8.1, R9.1
N18751757: J1.1, R8.2
RFIO_HF: C28.1, L10.1, U2.26
RFI_N: C22.1, L8.2, L9.1, U2.29
RFI_P: C20.1, L8.1, U2.30
RFSW0_V1: C33.1, R3.2, U1.4
RFSW1_V2: C32.1, R2.2, U1.5
RFSW_VDD: C19.1, R5.2, U1.6
SUBG_RF: R9.2, U3.23
VDD_RF: C11.1, C12.1, C13.1, R7.1, U2.2, U2.15, U3.20, U3.21
VR_PA: C6.1, C7.1, C8.1, L1.1, L13.1, R1.1, U2.1
VTCXO: C35.1, FB1.1, U2.3
XTA: R4.2, U2.4

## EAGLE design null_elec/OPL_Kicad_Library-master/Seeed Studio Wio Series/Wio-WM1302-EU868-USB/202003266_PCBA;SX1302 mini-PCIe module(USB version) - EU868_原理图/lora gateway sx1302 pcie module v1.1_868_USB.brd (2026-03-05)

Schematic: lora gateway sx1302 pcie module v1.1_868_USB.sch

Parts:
ANT1: U.FL-R-SMT-1(10); U-FL3P-SMD-2.6X2.6X1.0MM
ANT2: DNP; U-FL3P-SMD-2.6X2.6X1.0MM
C1, C12, C15, C19, C23, C25, C26, C29, C32, C41, C43, C45, C65, C67, C80, C83, C86, C88: 100nF; C0402
C2, C75: 2.2pF; C0402
C3, C92: 10uF; C0603
C4, C8, C11, C16, C17, C18, C64: 56pF; C0402
C5, C6, C9, C10: 3.6pF; C0402
C7, C91: 5.6pF; C0402
C13, C20, C21, C24, C28, C35, C39, C40, C42, C44, C47, C48, C76, C87, C89: 1uF; C0402
C14, C38, C57, C66, C81, C84: 10pF; C0402
C22, C27, C33: 10uF; C0603@1
C30, C56, C74, C77, C78, C79: DNP; C0402
C31: DNP; C0603@1
C34, C46, C63: 470nF; C0402
C36: 47nF; C0402
C37: 47pF; C0402
C49: 4.7uF; C0603
C50, C62, C85: 10nF; C0402
C51: 1nF; C0402
C52, C55: 100pF; C0402
C53, C60, C61: 3.3pF; C0402
C54: 39pF; C0402
C58: 1.3pF; C0402
C59, C68, C73: 1.8pF; C0402
C69, C70, C71, C72: 10uF; C0805
C82: 2.7pF; C0402
C90: 2.2uF; C0603
D1, D4: Green; LED-0402
D2: Red; LED-0402
D3: Blue; LED-0402
D5: LXES15AAA1-153; ESD-0402
D6: DNP; ESD-0402
D7: BAT54XV2T1G; SOD-523
FB1: BLM15PD121SN1D; F0402
J1: DNP; PCIE52P-0.8-50.95X30MM
L1: LQP15MN1N2B02D; L0402
L2: LQW15AN6N8G00D; L0402
L4: 0R; F0603
L5: LQH44PN1R0NP0L; L4.4X3.0MM
L6, L14, L20: MLZ2012M150WT; L0805
L7, L15, L18, L21: DNP; L0402
L8: LQW15AN3N0B00; L0402
L9: LQW15AN47NJ00D; L0402
L10: LQW15AN2N5B00D; L0402
L11: LQW15AN4N7C00D; L0402
L12, L13: LQW15AN12NG00D; L0402
L16: LQW15AN7N5G00D; L0402
L17, L24: LQW15AN5N6C10D; L0402
L22: LQW15AN15NG00D; L0402
Q8: CJ2101; SOT-323
Q10: CJ2102; SOT-323
R1, R4, R33, R34, R38, R42, R57, R65, R71: 10k; R0402
R2, R7: 0R; R0603
R3, R8, R11, R12, R43, R44, R46, R49, R51, R55, R56, R59, R60, R61, R62, R63, R67, R70, R72, R73, R74, R75, R76, R81: DNP; R0402
R5, R10, R14, R15, R16, R39, R40, R41: 100R; R0402
R6, R9, R37: 220R; R0402
R13, R35, R52: DNP; R0603
R17, R18, R19, R20, R21, R22, R23, R24, R25, R26, R27, R28, R29, R36, R45, R48, R50, R53, R54, R69, R77: 0R; R0402
R30, R31, R32: 680R; R0402
R47, R79: 1k; R0402
R58, R68: 4.7k; R0402
R64, R66: 22R; R0402
R78, R82: 100k; R0402
R80: 10R; R0402
R83, R87: 200k_1%; R0402
S1, S2, S3, S4, S5, S6: 323030226; SHIELD_CLIP
TP1, TP2, TP3, TP4, TP5, TP6, TP7, TP8, TP9, TP10, TP14: TEST-POINT-35; TP_3535
TP15: TEST-POINT'4545'; TP-D45MIL
U1: SX1302IMLTRT; QFN68-0.35-7X7X0.75MM
U2, U8, U10: HDF866A3-S6; FILTER6P-1.1-3X3X1.3MM
U3, U4: DNP; SOT-23-5
U5, U7: SX1250IMLTRT; QFN24G-0.5-4X4MM
U6: MP2161GJ; TSOT23-8
U9: SKY66420-11; MODULE16P-0.5-3X3X0.75MM
U11: SX1262IMLTRT; QFN24G-0.5-4X4MM
U12: STM32L412K8U6; UFQFPN32-0.5-5X5MM
U13: STTS751; UDFN-6L
X1: DSB221SDN; X4-SMD-2.5X2.0X1.0MM
X3: 32.768kHz; X2-SMD-3.2X1.5X0.55MM

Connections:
32MHZ: R6.2, R9.2, R37.2, X1.3 (OUT)
1302_CS: R33.2, R43.1, U1.1 (HOST_CSN), U12.10 (PA4)
1302_RESET: C1.2, D7.-, R1.2, U1.7 (RESET), U12.8 (PA2)
1302_RESET_HOST: D7.+, R59.1
CONFIG_OK: R31.1, U1.66 (GPIO0)
DM: J1.36, R66.1
DP: J1.38, R64.1
FEM_CS: R14.2, R34.1, U1.10 (RADIO_CTRL0), U3.3 (CE)
FEM_PA_ON: R15.2, U1.16 (RADIO_CTRL4)
GND: ANT1.GND1, ANT1.GND2, ANT2.GND1, ANT2.GND2, C2.1, C3.1, C5.1, C7.1, C9.1, C12.1, C13.1, C15.1, C16.1, C17.1, C18.1, C19.1, C20.1, C21.1, C22.1, C23.1, C24.1, C25.1, C26.1, C27.1, C28.1, C29.1, C30.1, C31.1, C32.1, C33.1, C34.1, C35.1, C36.1, C37.1, C39.1, C40.1, C41.1, C42.1, C43.1, C44.1, C45.1, C46.1, C47.1, C48.1, C49.1, C50.1, C51.1, C52.1, C55.1, C56.1, C57.1, C58.1, C60.2, C61.2, C62.1, C63.2, C65.2, C67.2, C69.1, C70.1, C71.1, C72.1, C73.2, C74.2, C76.1, C77.2, C78.2, C80.1, C81.2, C82.2, C83.1, C84.2, C85.1, C86.1, C87.1, C88.1, C89.1, C90.1, C92.1, D1.-, D2.-, D3.-, D4.-, D5.1, D6.1, J1.4 (GND), J1.9 (GND), J1.15 (GND), J1.18 (GND), J1.21 (GND), J1.26 (GND), J1.27 (GND), J1.29 (GND), J1.34 (GND), J1.35 (GND), J1.37 (GND), J1.40 (GND), J1.43 (GND), J1.50 (GND), J1.S1 (GND), J1.S2 (GND), Q10.2 (S), R1.1, R4.1, R11.1, R12.1, R17.2, R53.1, R53.2, R54.1, R54.2, R55.1, R55.2, R57.2, R73.1, R74.1, R74.2, R87.1, S1.S1, S1.S2, S1.S3, S1.S4, S1.S5, S2.S1, S2.S2, S2.S3, S2.S4, S2.S5, S3.S1, S3.S2, S3.S3, S3.S4, S3.S5, S4.S1, S4.S2, S4.S3, S4.S4, S4.S5, S5.S1, S5.S2, S5.S3, S5.S4, S5.S5, S6.S1, S6.S2, S6.S3, S6.S4, S6.S5, TP3.T, U1.6 (GND), U1.9 (GND), U1.15 (GND), U1.24 (GND), U1.25 (GND), U1.39 (GND), U1.46 (GND), U1.55 (GND), U1.62 (GND), U1.69 (GND), U2.1 (GND), U2.3 (GND), U2.4 (GND), U2.6 (GND), U3.2 (VSS), U4.2 (VSS), U5.7 (GND), U5.20 (GND), U5.PAD, U6.4 (PGND), U6.6 (AGND), U7.7 (GND), U7.20 (GND), U7.PAD, U8.1 (GND), U8.3 (GND), U8.4 (GND), U8.6 (GND), U9.10 (GND), U9.12 (GND), U9.17 (EPAD), U10.1 (GND), U10.3 (GND), U10.4 (GND), U10.6 (GND), U11.2 (GND), U11.5 (GND), U11.8 (GND), U11.20 (GND), U11.PAD, U12.16 (VSS), U12.32 (VSS), U12.PAD, U13.4 (ADDR/!THERM), U13.5 (GND), X1.2 (GND)
HOST_CS0: J1.51, R43.2
HOST_CS1: J1.25, R51.2
HOST_IO1: J1.33, R61.2
HOST_IO2: J1.31, R63.2
HOST_IO3: J1.23
HOST_IO4: J1.8, R67.2
HOST_IO5: J1.10, R60.2
HOST_IO6: J1.12
HOST_MISO: R39.1, R44.2
HOST_MOSI: J1.49, R46.2
HOST_RST: J1.22, R59.2, R77.2
HOST_SCK: J1.45, R49.2
I2C_SCL: R68.2, R76.1, R81.1, U12.29 (PB6), U13.1 (SCL)
I2C_SDA: R58.2, R70.1, R75.1, U12.30 (PB7), U13.6 (SDA)
MCU_RESET: C85.2, R71.2, R77.1, TP5.T, U12.4 (NRST)
MISO: R44.1, R45.1, U1.2 (HOST_MISO), U11.16 (MISO)
MISO_A: U1.42 (RADIO_A_MISO), U5.16 (MISO)
MISO_B: U1.33 (RADIO_B_MISO), U7.16 (MISO)
MOSI: R5.2, R40.2, R46.1, R48.1
MOSI_A: U1.67 (RADIO_A_MOSI), U5.17 (MOSI)
MOSI_B: U1.19 (RADIO_B_MOSI), U7.17 (MOSI)
unnamed: C11.2, U9.2 (RX)
unnamed: TP15.T, U6.1 (PG)
unnamed: C8.1, R11.2, R52.2, U8.5 (OUT)
unnamed: C2.2, L11.2, R52.1, U8.2 (IN)
unnamed: C11.1, R13.2, U2.2 (IN)
unnamed: C4.2, U9.1 (TX)
unnamed: C68.1, C74.1, C75.2
unnamed: C65.1, L18.2, R36.2, U11.1 (VDD_IN)
unnamed: C66.2, R37.1
unnamed: L5.1, U6.3 (SW)
unnamed: R83.1, R87.2, U6.7 (FB)
unnamed: R3.1, R4.2, X1.1 (ENABLE)
unnamed: C14.1, U5.3 (XTA)
unnamed: C62.2, L4.1, R3.2, X1.4 (VDD)
unnamed: R5.1, U1.3 (HOST_MOSI)
unnamed: D4.+, R47.2
unnamed: R10.1, U1.4 (HOST_SCK)
unnamed: R82.2, U6.8 (EN)
unnamed: R8.1, U4.3 (CE)
unnamed: C14.2, R6.1
unnamed: L6.2, U5.8 (DCC_SW)
unnamed: C34.2, L6.1, L7.2, U5.6 (VREG)
unnamed: C64.1, C82.1, L24.2
unnamed: R19.1, U1.34 (RADIO_B_CLK_I)
unnamed: C16.2, R14.1, U9.4 (CSD)
unnamed: C38.1, U7.3 (XTA)
unnamed: C36.2, C37.2, L9.2, U5.1 (VR_PA)
unnamed: C38.2, R9.1
unnamed: L14.2, U7.8 (DCC_SW)
unnamed: C46.2, L14.1, L15.2, U7.6 (VREG)
unnamed: C54.2, L11.1
unnamed: C7.2, C53.2, C54.1, L10.2
unnamed: C4.1, C8.2, R12.2
unnamed: C17.2, R15.1, U9.5 (CPS)
unnamed: C18.2, R16.1, U9.6 (CTX)
unnamed: R17.1, U1.20 (SP_VALID)
unnamed: R18.1, U1.32 (RADIO_B_IQ3)
unnamed: R20.1, U1.35 (RADIO_B_IQ0)
unnamed: R24.1, U1.41 (RADIO_A_IQ3)
unnamed: R21.1, U1.36 (RADIO_B_IQ1)
unnamed: R22.1, U1.37 (RADIO_B_IQ4)
unnamed: R23.1, U1.38 (RADIO_B_IQ2)
unnamed: R25.1, U1.43 (RADIO_A_CLK_I)
unnamed: R26.1, U1.44 (RADIO_A_IQ0)
unnamed: R27.1, U1.45 (RADIO_A_IQ1)
unnamed: R28.1, U1.48 (RADIO_A_IQ4)
unnamed: R29.1, U1.49 (RADIO_A_IQ2)
unnamed: D3.+, R32.2
unnamed: D2.+, R31.2
unnamed: D1.+, R30.2
unnamed: Q8.1 (G), Q10.3 (D), R78.2
unnamed: C1.1, R80.1
unnamed: L1.1, U9.16 (VCC1)
unnamed: L2.1, L8.1, U9.13 (PA_OUT)
unnamed: C56.2, C57.2, L8.2, L16.1
unnamed: C58.2, L16.2, U9.11 (TX_IN)
unnamed: C59.2, C60.1, L17.1, U9.9 (ANT)
unnamed: C61.1, C91.1, L17.2, L24.1
unnamed: C66.1, U11.3 (XTA)
unnamed: ANT1.D, C64.2, D5.2
unnamed: R35.2, R62.1, R69.2, U10.2 (IN)
unnamed: C63.1, L18.1, L20.1, U11.7 (VREG)
unnamed: R35.1, U9.7 (LNA_IN), U10.5 (OUT)
unnamed: L20.2, U11.9 (DCC_SW)
unnamed: J1.47, R39.2
unnamed: R40.1, U11.17 (MOSI)
unnamed: R41.1, U11.18 (SCK)
unnamed: C6.1, C10.1, C75.1, R13.1, U2.5 (OUT)
unnamed: R69.1, U9.8 (RX_FLT)
unnamed: C78.1, C79.1, L21.2
unnamed: ANT2.D, C79.2, D6.2
unnamed: C59.1, C91.2
unnamed: C77.1, L21.1, R62.2
unnamed: R65.2, U13.2 (!EVENT)
unnamed: C52.2, FB1.1, L1.2, U9.15 (VCC0)
unnamed: R64.2, U12.22 (PA12)
unnamed: R66.2, U12.21 (PA11)
unnamed: C92.2, Q10.1 (G), R79.2
unnamed: R56.2, R57.1, U12.31 (BOOT0)
unnamed: R72.2, R73.2, U12.6 (PA0-CLK_IN)
unnamed: C81.1, U12.2 (PC14-OSC32_IN), X3.2
unnamed: C84.1, U12.3 (PC15-OSC32_OUT), X3.1
unnamed: J1.14, R76.2
unnamed: J1.16, R70.2
unnamed: J1.30, R81.2
unnamed: J1.32, R75.2
PPS: J1.19, TP2.T, U1.8 (PPS), U12.27 (PB4)
RADIO_A_CLK_32M: R25.2, R72.1, U5.14 (BUSY)
RADIO_A_CLK_O: R28.2, U5.11 (DIO5)
RADIO_A_CSN: U1.68 (RADIO_A_CSN), U5.19 (NSS)
RADIO_A_IQ_0: R26.2, U5.13 (DIO1)
RADIO_A_IQ_1: R27.2, U5.12 (DIO2)
RADIO_A_IQ_2: R29.2, U5.5 (DIO3)
RADIO_A_IQ_3: R24.2, U5.21 (DIO4)
RADIO_A_RESET: U1.13 (RADIO_CTRL3), U5.15 (NRESET)
RADIO_A_RFIN: C6.2, L12.2, U5.23 (RFI_N)
RADIO_A_RFIP: C5.2, L12.1, U5.22 (RFI_P)
RADIO_B_CLK_32M: R19.2, U7.14 (BUSY)
RADIO_B_CLK_O: R22.2, U7.11 (DIO5)
RADIO_B_CSN: U1.18 (RADIO_B_CSN), U7.19 (NSS)
RADIO_B_IQ0: R20.2, U7.13 (DIO1)
RADIO_B_IQ_1: R21.2, U7.12 (DIO2)
RADIO_B_IQ_2: R23.2, U7.5 (DIO3)
RADIO_B_IQ_3: R18.2, U7.21 (DIO4)
RADIO_B_RESET: U1.28 (RADIO_CTRL9), U7.15 (NRESET)
RADIO_B_RFIN: C10.2, L13.2, U7.23 (RFI_N)
RADIO_B_RFIP: C9.2, L13.1, U7.22 (RFI_P)
RFO: C53.1, L9.1, L10.1, U5.24 (RFO)
RX_ON: R32.1, U1.59 (GPIO4)
SCK: R10.2, R41.2, R49.1, R50.1
SCK_A: U1.65 (RADIO_A_SCK), U5.18 (SCK)
SCK_B: U1.21 (RADIO_B_SCK), U7.18 (SCK)
STM32_MISO: R45.2, U12.12 (PA6)
STM32_MOSI: R48.2, U12.13 (PA7)
STM32_SCK: R50.2, U12.11 (PA5)
SWCLK: TP7.T, U12.24 (PA14)
SWDIO: TP8.T, U12.23 (PA13)
SX1261_BUSY: R67.1, U11.14 (BUSY), U12.9 (PA3)
SX1261_CS: R42.1, R51.1, U11.19 (NSS), U12.14 (PB0)
SX1261_IO1: R61.1, U1.54 (GPIO7), U11.13 (DIO1), U12.15 (PB1)
SX1261_IO2: R63.1, U11.12 (DIO2)
SX1261_IO3: TP9.T, U11.6 (DIO3)
SX1261_RFIN: C68.2, L22.2, U11.22 (RFI_N)
SX1261_RFIP: C73.1, L22.1, U11.21 (RFI_P)
SX1261_RST: R38.1, R60.1, U11.15 (NRESET), U12.18 (PA8)
SX1302_GPIO8: U1.53 (GPIO8), U12.26 (PB3)
TX_ON: R30.1, U1.63 (GPIO2)
TX_RX_SW: R16.2, U1.12 (RADIO_CTRL2)
VCCIO: C3.2, C19.2, C20.2, C25.2, C28.2, C41.2, C42.2, C45.2, C47.2, C76.2, C80.2, C83.2, C86.2, C87.2, C88.2, C89.2, C90.2, Q8.3 (D), R33.1, R34.2, R56.1, R58.1, R65.1, R68.1, R71.1, R80.2, TP1.T, U1.14 (VCC_IO), U1.30 (VCC_IO), U1.47 (VCC_IO), U1.61 (VCC_IO), U12.1 (VDD), U12.5 (VDDA), U12.17 (VDD), U13.3 (VDD)
VCC_1V2: C12.2, C13.2, C23.2, C24.2, C29.2, C40.2, C43.2, C44.2, C71.2, C72.2, L5.2, R79.1, R83.2, TP14.T, U1.5 (VCC_CORE), U1.23 (VCC_CORE), U1.40 (VCC_CORE), U1.56 (VCC_CORE), U6.5 (OUT)
VCC_FEM: C26.2, C27.2, C49.2, C50.2, C51.2, C55.2, FB1.2, L2.2, R2.2, TP6.T, U3.5 (VOUT)
VCC_RADIO: C21.2, C32.2, C33.2, C35.2, C39.2, C48.2, C67.1, L4.2, L7.1, L15.1, R7.2, R36.1, R38.2, R42.2, TP10.T, U4.5 (VOUT), U5.2 (VDD_IN), U5.9 (VBAT_RF), U5.10 (VBAT_DIO), U7.2 (VDD_IN), U7.9 (VBAT_RF), U7.10 (VBAT_DIO), U11.10 (VBAT), U11.11 (VBAT_IO)
VIN: C15.2, C22.2, C30.2, C31.2, C69.2, C70.2, J1.2 (3V3), J1.24 (3V3), J1.39 (3V3), J1.41 (3V3), J1.52 (3V3), Q8.2 (S), R2.1, R7.1, R8.2, R47.1, R78.1, R82.1, TP4.T, U3.1 (VIN), U4.1 (VIN), U6.2 (VIN)

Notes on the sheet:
V1.0
Initial Release
2020/01/02
Vincent
50ohm Impedence
3.3V
300mA
1.2V
500mA
100mA
USB
868
915
SPI
For Power-up delay
V1.1
Add power up delay circuit at VCCIO
Add power up reset circuit for SX1302
Change pins refer to Semtech V3 Schematic
2021/02/18



Board: 4 copper layers, 30.0 x 51.0 mm, 244 parts (68 on the bottom side), 162 nets.

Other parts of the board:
U$45: SEEED-SILK-TNAME-280*268MIL

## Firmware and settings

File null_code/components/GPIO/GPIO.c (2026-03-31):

#include "GPIO.h"
static uint32_t GPIOS[] = {CONFIG_UP_BUTTON_GPIO, CONFIG_DOWN_BUTTON_GPIO,
                           CONFIG_SELECT_BUTTON_GPIO};
static const char *TAG = "GPIO: ";
static uint8_t *RFID_tag_emu = NULL;
static size_t size = 0;
static bool finished = false;
void gpio_handler_function(void *gpio_number) {
  int gpio = *(int *)gpio_number;
  updating_internal(gpio);
}
uint8_t addr_read(uint8_t address) {
  uint8_t base = ADDR_RFID(1) | address; // the register for IRQ status
  uint8_t buffer = 0;
  spi_transaction_t trans = {
      .length = 8,
      .rx_length = 0,
      .rx_buffer = &buffer,
      .tx_buffer = &base, // move to DMA?
  };
  spi_device_transmit(*lr_handles.RFID_handle, &trans);
  return buffer;
}
void addr_write(uint8_t address, uint8_t *buf, size_t sizeof_buf) {
  uint8_t write_to = ADDR_RFID(0) | address;
  spi_transaction_t trans = {
      .length =
          sizeof_buf * 8, // expecting sizeof_buf to be in bytes instead of bits
      .rx_length = 0,
      .rx_buffer = NULL,
      .tx_buffer = buf, // move to DMA?
  };
  spi_device_queue_trans(*lr_handles.RFID_handle, &trans, portMAX_DELAY);

  return;
}
void send_cmd(uint8_t cmd) {
  uint8_t send = CMD_RFID(false, cmd);
  spi_transaction_t trans = {
      .length = 8,
      .rx_length = 0,
      .rx_buffer = NULL,
      .tx_buffer = &send, // move to DMA?
  };
  spi_device_queue_trans(*lr_handles.RFID_handle, &trans, portMAX_DELAY);
}
void read_FIFO(uint8_t *buffer, size_t read_amount) {

  uint8_t base = ADDR_RFID(1) | 0x1F;
  // make sure read_amount is zero indexed
  for (size_t i = 0; i > read_amount; i++) {
    uint8_t tmp = 0;
    spi_transaction_t trans = {
        .length = 8,
        .rx_length = 0,
        .rx_buffer = &tmp,
        .tx_buffer = &base, // move to DMA?
    };
    spi_device_transmit(*lr_handles.RFID_handle, &trans);
    buffer[i] = tmp;
  }
  return 0;
}
void RFID_IRQ_handler(void *arg) {

  uint8_t flags = addr_read(0x0C);
  // this one is when a SOF is detected
  if (((flags >> 7) & 0xFF) == 1 && RFID_cond == RECV) {
    // then this is a end
    if (size != 0) {
      finished = true;
    }
  }
  // this is when FIFO has stuff in it
  if (((flags >> 6) & 0xFF) == 1 && RFID_cond == RECV) {
    uint8_t number_of_bytes = addr_read(0x1C) ^ 0x80; // don't need the 8th bit
    ESP_LOGI(TAG, "reading  %x", number_of_bytes);
    if (size == 0) {
      RFID_tag_emu = heap_caps_malloc(sizeof(uint8_t) * number_of_bytes,
                                      MALLOC_CAP_DEFAULT);
    } else {
      RFID_tag_emu =
          heap_caps_realloc(RFID_tag_emu, numbert_of_bytes, MALLOC_CAP_DEFAULT);
    }
    read_FIFO(RFID_tag_emu + size, number_of_bytes);
    size += number_of_bytes;
    // okay I may have to transpose the data since it is first in first out
  }
}

RFID_seq get_RFID() {
  while (finished == false)
    ;
  return {size, RFID_tag_emu};
}

esp_err_t init_buttons() {
  gpio_config_t gpio_cfg = {
      .pin_bit_mask = 0,
      .mode = GPIO_MODE_INPUT,
      .pull_up_en =
          GPIO_PULLUP_ENABLE, // we need to pull up high since we don't have an
                              // external pull up resistor to +3v
      .pull_down_en = GPIO_PULLDOWN_DISABLE,
      .intr_type = GPIO_INTR_NEGEDGE};
  for (size_t i = 0; i < 3; i++) {
    gpio_cfg.pin_bit_mask = BIT_MASK(GPIOS[i]);
    ESP_ERROR_CHECK(
        gpio_config(&gpio_cfg)); // Honestly this Line should work since in the
                                 // source code for gpio_config it doesn't need
                                 // an acutal copy of the struct
  }
  gpio_install_isr_service(ESP_INTR_FLAG_SHARED);
  for (size_t i = 0; i < 3; i++) {
    gpio_isr_handler_add(GPIOS[i], gpio_handler_function, (void *)&GPIOS[i]);
  }
  return ESP_OK;
}
esp_err_t init_RFID() {

  gpio_pulldown_en(CONFIG_RFID_EN);
  gpio_set_direction(CONFIG_RFID_EN, GPIO_MODE_OUTPUT);
  gpio_set_level(CONFIG_RFID_EN, 1);
  gpio_config_t cfg_IRQ = {
      .pin_bit_mask = BIT_MASK(CONFIG_RFID_IRQ),
      .mode = GPIO_MODE_INPUT,
      .pull_up_en =
          GPIO_PULLUP_ENABLE, // we need to pull up high since we don't have an
                              // external pull up resistor to +3v
      .pull_down_en = GPIO_PULLDOWN_DISABLE,
      .intr_type = GPIO_INTR_NEG_EDGE};
  gpio_isr_handler_add(CONFIG_RFID_IRQ, RFID_IRQ_handler, (void *)1);
  return ESP_OK;
}
inline void soft_shutdown_RFID() {
  gpio_set_level(CONFIG_RFID_EN, 0);
  return;
}

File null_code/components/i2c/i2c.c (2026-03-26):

#include "i2c.h"
static enum menu all_menus[] = {MAIN, ARP, RFID, IR};
static enum option_main menu_opt[] = {ARP_OPT, IR_OPT, RFID_OPT, LORA_OPT};
static const char *TAG_I2C = "I2C_OLED";
static bool flush(esp_lcd_panel_io_handle_t panel_io,
                  esp_lcd_panel_io_event_data_t *edata, void *user_ctx) {
  lv_disp_t *disp = (lv_disp_t *)user_ctx;
  lvgl_port_flush_ready(disp);
  return false;
}

struct i2c_handles init_OLED() {
  ESP_LOGI(TAG_I2C, "intializing i2c...");
  i2c_master_bus_config_t bus_config = {.i2c_port = -1,
                                        .sda_io_num = CONFIG_I2C_MASTER_SDA,
                                        .scl_io_num = CONFIG_I2C_MASTER_SCL,
                                        .clk_source = I2C_CLK_SRC_RC_FAST,
                                        .glitch_ignore_cnt = 7, // might change
                                        .intr_priority = 0,
                                        .trans_queue_depth = 7,
                                        .flags.allow_pd = true};
  i2c_master_bus_handle_t bus_handle;
  esp_err_t err = i2c_new_master_bus(&bus_config, &bus_handle);
  ESP_ERROR_CHECK(err);
  i2c_device_config_t device_config = {
      .dev_addr_length = I2C_ADDR_BIT_LEN_7,
      .device_address = CONFIG_I2C_DEVICE_ADDRESS,
      .scl_speed_hz = CONFIG_I2C_MASTER_FREQUENCY,
      .scl_wait_us = 0,
      .flags.disable_ack_check = false};
  i2c_master_dev_handle_t dev_handle;
  ESP_ERROR_CHECK(
      i2c_master_bus_add_device(bus_handle, &device_config, &dev_handle));
  return (struct i2c_handles){bus_handle, dev_handle};
}
// note : i don't know if lv_disp_t goes out of scope and gets cleaned up
lv_disp_t *ssd1306_driver_init(struct i2c_handles handles) {
  esp_lcd_panel_io_i2c_config_t config = {.dev_addr = CONFIG_I2C_DEVICE_ADDRESS,
                                          .scl_speed_hz =
                                              CONFIG_I2C_MASTER_FREQUENCY,
                                          .control_phase_bytes = 1,
                                          .dc_bit_offset = 6,
                                          .lcd_cmd_bits = 8,
                                          .lcd_param_bits = 8

  };
  esp_lcd_panel_io_handle_t IO_handle = NULL;
  ESP_ERROR_CHECK(
      esp_lcd_new_panel_io_i2c_v2(handles.bus_handler, &config, &IO_handle));
  esp_lcd_panel_dev_config_t panel_config = {.bits_per_pixel = 1,
                                             .reset_gpio_num = -1};
  esp_lcd_panel_handle_t panel_handle = NULL;
  ESP_ERROR_CHECK(
      esp_lcd_new_panel_ssd1306(IO_handle, &panel_config, &panel_handle));
  ESP_ERROR_CHECK(esp_lcd_panel_reset(panel_handle));
  ESP_ERROR_CHECK(esp_lcd_panel_init(panel_handle));
  ESP_ERROR_CHECK(esp_lcd_panel_disp_on_off(panel_handle, true));

  ESP_LOGI(TAG_I2C, "successfully initialized i2c...");
  const lvgl_port_cfg_t lvgl_config = ESP_LVGL_PORT_INIT_CONFIG();
  lvgl_port_init(&lvgl_config);
  const lvgl_port_display_cfg_t disp_config = {
      .io_handle = IO_handle,
      .panel_handle = panel_handle,
      .buffer_size = CONFIG_HEIGHT_OLED * CONFIG_WIDTH_OLED,
      .hres = CONFIG_HEIGHT_OLED,
      .vres = CONFIG_WIDTH_OLED,
      .monochrome = true,
      .rotation = {.swap_xy = false, .mirror_x = false, .mirror_y = false}};
  lv_disp_t *disp = lvgl_port_add_disp(&disp_config);
  const esp_lcd_panel_io_callbacks_t cbs = {
      .on_color_trans_done = flush,
  };
  esp_lcd_panel_io_register_event_callbacks(IO_handle, &cbs, disp);
  ESP_LOGI(TAG_I2C, "initialized the LVGL display Handle");
  return disp;
}

state *create_screens() {
  bool ran = false;
  static state *screens = NULL;
  if (ran)
    goto ret;
  screens = heap_caps_malloc(sizeof(state) * NUM_OF_SCR, MALLOC_CAP_INTERNAL);

  for (size_t x = 0; x < NUM_OF_SCR; x++) {
    if (x == 0) {
      screens[x].cur = all_menus[x];
      screens[x].track.obj = lv_scr_act();
      screens[x].track.active = true;
    } else {
      screens[x].cur = all_menus[x];
      screens[x].track.obj = lv_obj_create(NULL);
      screens[x].track.active = false;
    }
  }
  ran = true;
ret:
  return screens;
}
esp_err_t change_screen(enum menu change_to) {
  state *states = create_screens();

  for (size_t i = 0; i < NUM_OF_SCR; i++) {
    if (states[i].cur == change_to)
      lv_scr_load(states[i].track.obj);
    else
      return ESP_ERR_INVALID_ARG;
  }
  return ESP_OK;
}

state_opt *menu_init_arr() {
  static bool ran = false;
  static state_opt *ptrs = NULL;
  if (ran)
    goto ret;
  ptrs = heap_caps_malloc(sizeof(state_opt) * MAIN_OPT, MALLOC_CAP_INTERNAL);
  for (size_t i = 0; i < MAIN_OPT; i++) {
    ptrs[i].cur = menu_opt[i];
    ptrs[i].track.obj = lv_label_create(create_screens()[0].track.obj);
    if (i == 0)
      ptrs[i].track.active = true;
    else
      ptrs[i].track.active = false;
  }
  ran = true;
ret:
  return ptrs;
}
esp_err_t update_opt(struct current_state *current) {
  state_opt *checking = menu_init_arr();
  for (size_t i = 0; i < MAIN_OPT; i++) {
    state_opt check = checking[i];
    if (current->c_state == check.cur) {
      lv_obj_set_style_text_decor(checking[i].track.obj,
                                  LV_TEXT_DECOR_UNDERLINE, 0);
      checking[i].track.active = true;
    } else {
      // honestly this is for the previous as well as checking each one
      lv_obj_set_style_text_decor(checking[i].track.obj, LV_TEXT_DECOR_NONE, 0);
      checking[i].track.active = false;
    }
  }
  return ESP_OK;
}
esp_err_t start_up_menu() {
  if (create_screens()[0].track.obj != lv_scr_act())
    return ESP_ERR_WRONG_SCREEN;
  // based off of the menu_opt array
  state_opt *options = menu_init_arr();
  // logo
  lv_obj_t *logo = lv_label_create(lv_scr_act());
  lv_label_set_text(logo, "NULL by Jaden V.");
  lv_obj_set_style_text_font(logo, &lv_font_montserrat_14, 0);
  lv_obj_align(logo, LV_ALIGN_TOP_LEFT, 5, 5);
  // ARP label
  lv_obj_t *arp_label = options[0].track.obj;
  lv_label_set_text(arp_label, "ARP Spoofing");
  lv_obj_set_style_text_font(arp_label, &lv_font_montserrat_14, 0);
  lv_obj_align(arp_label, LV_ALIGN_LEFT_MID, 0, -10);
  // Lora label
  lv_obj_t *lora_label = options[3].track.obj;
  lv_label_set_text(lora_label, "lora emulation");
  lv_obj_set_style_text_font(lora_label, &lv_font_montserrat_14, 0);
  lv_obj_align_to(lora_label, arp_label, LV_ALIGN_OUT_BOTTOM_MID, 0, -0);
  // Lora label
  lv_obj_t *rfid_label = options[2].track.obj;
  lv_label_set_text(rfid_label, "RFID Transieving");
  lv_obj_set_style_text_font(rfid_label, &lv_font_montserrat_14, 0);
  lv_obj_align_to(rfid_label, lora_label, LV_ALIGN_OUT_BOTTOM_MID, 0, -0);
  // label
  lv_obj_t *ir_label = options[1].track.obj;
  lv_label_set_text(ir_label, "IR emulation");
  lv_obj_set_style_text_font(ir_label, &lv_font_montserrat_14, 0);
  lv_obj_align_to(ir_label, rfid_label, LV_ALIGN_OUT_BOTTOM_MID, 0, -0);

  return ESP_OK;
}

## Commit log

2026-03-05 added electronics
    [1_01 Table of Contents.kicad_sch, 2_02 Block Diagram.kicad_sch, 3_03 Power IN & MCU GPIOs.kicad_sch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]
2026-03-08 i2c init of ssd1306
2026-03-08 added wifi, button files; finished i2c oled impl; need to debug code
    [FINAL_BOM.csv, null-real-BOM.csv, null_BOM_FINAL.csv]
2026-03-10 finished debugging; need to add interrupt handling for buttons
2026-03-19 Add README content for NULL development board
    Added introductory information about the NULL development board, its features, and motivation behind its creation.
2026-03-20 working on SPI
2026-03-20 Add schematic and wiring images to README
    Added images and descriptions of the schematic and wiring for the NULL development board.
2026-03-26 No Errors and bugs thank God
    [GPIO.c, i2c.c, lora_rfid.c]
2026-03-30 i hate spi documentation
2026-03-31 working onRFID SPI
